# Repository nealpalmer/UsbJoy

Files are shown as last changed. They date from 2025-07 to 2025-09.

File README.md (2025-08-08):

# UsbJoy
USB Joystick Controller 12Digital/SmartButton, 4Analog, 1Rotary, 1NeoPixel

This is a couple of circuit boards that make up a fancy USB joystick controller for FRC #2984.
It has both a HID joystick interface and a HID uart interface (for configuration) presented to the computer (i.e. it works in Windows and Linux).  No embedded programming experience is necessary to get it to work!  It also looks like just a HID analog joystick to Windows.

To add to this readme+files:
- mechanical drawing of the board (wid, hei, hole locations)
- photo of driver's panel
- update code when I'm done fiddling with stuff
- Add pictures where appropriate (pickit programming, USB programming cable)
- A description of how to get feedback from the robot to the leds.  Does this require a networktables application?  Or use Force-Feedback mechanisms?






# Features:
- 12 Digital inputs for buttons (3-pin White/Yellow/Green JST XH: 5V, signal with 10k pullup, GND)
  - 12 is probably enough buttons for a FRC operator panel.  We use 2x of these on the operator panel, and 1 on the driver panel.
  - simple buttons and switches can be used, just connect to the 'signal' and 'GND' pins of the 3-pin connector, and ignore the '5V' pin.
- 4 Analog inputs for joysticks or linear/rotary potentiometers (10k ohms) (3-pin Blue JST XH: 5V, signal with 100k+100k pullup+pulldown, GND).
  - 1 Analog [joystick](https://www.amazon.com/dp/B08CGYGMJL) for driving (X & Y)
  - 2 [linear potentiometers](https://www.amazon.com/dp/B07HNY7VWC) are useful for controlling speeds or small adjustments to some positioning
  - There are more analog input pins that could be used for more analog inputs, but that is left upto the user to figure out if they care.  But it is probably simpler/cheaper just to make more of these boards.
- 1 Digital input can be used to drive a NeoPixel string (be careful of 500mA fuse) (3-pin Yellow)
  - Can mimic the robots LEDs (in case you can't see the robot)
  - Can give you feedback as to some positioning (i.e. target is to the left/right or up/down, and by how much)
  - Can give you feedback as to if you are holding the playing piece.
- 4-pin JST XH rotary encoder for Z-axis (600 ppr*4phase = 2400/rev resolution assumed)
  - We use the rotary encoder to control the angle that the robot is pointing on the field.  Turn the rotary knob by 5degrees, and the robot also turns by 5degrees...
- 4or5 extra 'virtual' buttons, 1 toggling (optional), 4 as constants
  - 4 virtual constant buttons make it possible to distinguish between multiple controllers easily.
  - Multiple UsbJoy boards can be distinguished from each other from the FRC Robot software (just use those constant buttons).  This means we don't have to re-arrange the joystick order in driver station.
- Arduino Pro Micro USB-C 5V ATmega32U4 controller board used for ease of soldering.
  - Make sure to get one with the fuse on the TOP side of the board (i.e. no bottom side components).  [amazon.com](https://www.amazon.com/gp/product/B0B6HYLC44)
- SmartButton support for all 12 Digital inputs
  - You can choose what each button's LED looks like for informational purposes.
  - Flickering the button when initially pressed is simple feedback that the button should be working (commuincation to UsbJoy, LED works, button works, cable connected appropriately).
  - Having the button light up when it should be useable is useful (i.e. the playing piece is being held, you can now press the shoot button).
  - Have a couple of buttons light up to indicate the state of the robot.
- 4 Digital connectors (Green) can have their 5V power switched on/off for use with simple led outputs (SmartButton requires it to always be powered on).
  - This sounded like a great idea initially, but I don't see a use for it now...
- ESD diodes on all 16 3-pin connectors
- Configuration of SmartButton settings done through the USB-UART interface.
  - Some settings are saved in EEPROM (Neopixel length, LED starting value, joystick invert axis, ...) , some are temporary (LED current values, neopixel pattern).
  - The settings are stored in the UsbJoy's EEPROM, and are configured for that particular port.  The settings aren't saved in the SmartButton itself.
  - You could compile different firmware for each button, and fix each button's LED functionality that way.
- Programming of PIC micro-controller done over USB-UART with MCLRn button press required (don't have anything plugged into J8, J11, J12).
- Programming of SmartButton PIC micro-controller over USB-UART (use a custom cable from J8+J11+J12 to SmartButton 5-pin header).
- Colored JST-XH 3-pin connectors are available on [aliexpress.com](https://www.aliexpress.us/item/3256806937445015.html)
- Colored JST-XH terminal 3-pin connectors are available on [aliexpress.com](https://www.aliexpress.us/item/3256804014172692.html)
- pre-crimped 3-pin cables are available on [aliexpress.com](https://www.aliexpress.us/item/3256807213104605.html)  Just be aware that the pins have to be removed, and swapped so that it is a 1:1 cable instead of a 1:3 cable (or you are going to connect GND to 5V, and destroy your SmartButtons).
- pre-crimped 10-pin cables are available on [amazon.com](https://www.amazon.com/dp/B0B2RCW5JF) And you would have to replace the connectors with a 3-pin version (cheap, and comes from US, so comes quickly).

# UsbJoy Connector description
- 
- J1-J12 are the button inputs.  Pin 1: 5V (square pad), Pin 2: 'signal' (short to GND during button press), Pin 3: GND.
- J7-J10 (Green connectors) can have their 5V pin switched on/off if you want to use an LED directly connected instead of a SmartButton.  They have a 100ohm series resistor for the 5V output to limit it to about 25mA (plenty for a SmartButton).
- J12 can be setup to drive a neopixel string (a programmable strip of RGB leds).  Be aware that the max current for the string should be about 400mA, any higher and the 500mA USB fuse on the Pro Micro is likely to blow.  So for very long strings, external power should be provided for the array.
- J13-J16 are the analog inputs.  Pin 1: 5V, Pin 2: analog signal, Pin 3: GND.
- J17 is the encoder input.  Pin 1: 5V (square pad), Pin 2,3: A&B encoder inputs, Pin 4: GND.  Any AB encoder can be used.  The firmware is setup to make a reasonable output for a 600 pulse/revolution=2400 change/revolution encoder (i.e. Z-axis has a range of 0-2399).  You can change the 2400 limit to any other number in the code for both the Arduino and PIC to make a different resolution encoder look right.
- J8, J11, J12 are used for PIC programming (both the UsbJoy and SmartButton PIC).
- Button between J17 and J5 is the PIC MCLRn button that connects J8.signal to MCLRn so that it is possible to program the PIC.
- J18 (5-pin holes on back side) is the PIC ICSP header.  Connect the PICKIT5 here.  You must disconnect PICKIT5 for normal operation.

# Rotary Encoder
- Uses a simple 4-pin {5V,A,B,GND} [encoder](https://www.amazon.com/dp/B01MZ4V1XP)
- 600pulses/revolution * 4 edges per pulse = 2400 positions/revolution (about 1/6degree resolution)
- Returns 0-2399 as the Z-axis to the Joystick HID interface.

# SmartButton features
- About $1 for circuit board+cpu+connector.  About $2 per illuminated arcade button.
- Designed to solder directly to 30mm illuminated arcade buttons. [amazon EG-Starts Illuminated 30mm](https://www.amazon.com/EG-STARTS-Illuminated-Buttons-Raspberry/dp/B01N11BDX9) [Aliexpress 30mm](https://www.aliexpress.us/item/3256804217382377.html) [Coin/1P/2P](https://www.aliexpress.us/item/2251832825468632.html) [AutoRGB](https://www.aliexpress.us/item/3256805580977933.html) [50pack 28mm](https://www.aliexpress.us/item/3256805775007172.html) [Free ship $10](https://www.aliexpress.us/item/2251832849688596.html)
- NOTE: 24mm illuminated buttons don't work, the pins are too close together and the button binds when the board is connected (unless you pre-bend the pins).  And they are only 1mm smaller diameter for the nut, so no reason to use them.
- Other buttons could be used.  Just solder the switch pins to the button, and the LED pins to an LED+Resistor.
- 3-pin interface (5V, signal, GND)
- Some solder jumpers can be filled, and some jumpers cut to turn a smart button into a dumb button (i.e. no 5V present).
- State of the led_option is stored in UsbJoy, and associated with the port.  So the buttons don't have to store their operational state.
- Programming of pic16f15213 can be done with either PicKit5 or UsbJoy.
- LED options
  - 0: OFF
  - 1: ON
  - 2: ON for 100ms when button gets pressed
  - 3: ON while button is pressed
  - 4: FLASHING 100ms on/100ms off
  - 5: SIN()
  - 6: FLASHING while button is pressed
  - 7: Button toggles state each time it is pressed: LED lit when in 'pressed' state
  - 8: Button toggles state each time it is pressed: LED flashes when in 'pressed' state
  - 9: you can add more if you want...

# NeoPixel
- Uses an off-the-shelf neopixel array (WS2812B 5V leds) [Strip_of_leds](https://www.amazon.com/dp/B09PBHJG6G) [ring_of_leds](https://www.amazon.com/dp/B08GPWVD57)
- Takes over Digital input #11 (the Yellow connector)
- You are going to have to make a cable that has the JST XH connector on the end of it.
- You MUST pay attention to the current draw of the string.  The entire UsbJoy is limited to 500mA, and if you draw much more than that, the fuse will blow, and everything will stop working.  So make sure that the length of string can't draw too much power.
- Possibly add an external power connection to power the neopixel array.
- Color choices:
  - 0x00-0x3f: Black-to-White solid color choices (4 values per R,G,B)
  - 0x80-0xff: Single white LED on (can be set to match the rotary encoder)
  - Rainbow
  - Moving Rainbow

# Files included:
- UsbJoy_d12_a4_r-rev2/: Kicad layout files, and gerbers
- SmartButton-rev2/: Kicad layout files, and gerbers
- UsbJoy_bill_of_materials.csv: spreadsheets with all of the parts to purchase and quantities and ordering links, pcb, buttons, cables, other stuff...
- mechanics/: openscad & STL files for a couple of mounts for UsbJoy using the SmartButton, rotary dial, 
- software/SmartButton_firmware/:
- software/UsbJoy_firmware/: firmware for the Atmega32U4 microcontroller
- software/UsbJoy_pic_firmware/: firmware 
- software/program_pic/: small application to program the pic16f1778 on UsbJoy, and pic15f15213 on SmartButton

# Manufacturing suggestions:
- [oshpark.com](https://oshpark.com/) has wonderful pricing for qty3 of 2and4 layer boards and ships in 10 calendar days for almost everything (and you can pay more to get it earlier, or pay for faster shipping)
  - [UsbJoy_R2](https://oshpark.com/shared_projects/QPZCB1ZT) board order $20/3 boards
  - [SmartButton_R2](https://oshpark.com/shared_projects/OV1uAkH7) board order $1.70/3 boards ($6.80/12 boards)
- A 3d-printer can make the UsbJoy board attach directly to the screw threads of one of the buttons.  A couple of sample mount's source files are [here](https://makerworld.com/en/models/1602536-usbjoy-controller-mount-30mm-arcade-button).
- An 3d printed [encoder spring](https://makerworld.com/en/models/1602721-rotary-encoder-rotary-friction-spring) makes the encoder much better for not spinning the robot wildly.
- An [acrylic wheel](https://makerworld.com/en/models/1605249-encoder-finger-wheel) with finger holes for the encoder is very useful.
- Testing for button functionality can be done in windows with the built-in "USB game controllers"->properties window to see the buttons that get pressed. NEED A PICTURE HERE!
- You can extract a 3d model of the boards from kicad to use in your 3d cad system.  Kicad: File->Export->STEP
- digikey has all of the electrical components necessary (except for the LED and Arduino board).
- 3x UsbJoy parts kit
- 12x SmartButton parts kit
- The arduino pro micro has a 0.5A fuse on it.  The bottom side of the board will NOT be accessible.  If that 0.5A fuse is on the bottom side, and you have over current, then your boards will not be salvageable.  So get a version that has all the components on the top side.
- The discrete components are 0603 packages for easier soldering.
- Get some [illuminated magnifying glasses](https://www.amazon.com/YOCTOSUN-Magnifying-Rechargeable-1-5X-3-5X-Magnifier/dp/B0D8J3TYL3) for ease of soldering of small components. 
- Solder all of the SMT components before any thru-hole components.  Required for both boards, because some of the thru-hole soldering will make SMT parts unreachable.

# How to program Arduino Pro Micro's Atmega32U4 (the USB device):
- Run the [Arduino GUI](https://www.arduino.cc/en/software/) version 1.8.19 (or newer than May 2025).
- Load the *.ino file
- Set up the board to be "Arduino Leonardo".
- Plug in the board into USB, then select the right Com port in the Arduino GUI.
- "Upload" 
 from the Arduino GUI.
- Programming does not clear the EEPROM, so any settings should remain unaffected.

# How to program pic16f1778 on UsbJoy using PICKIT5 programmer:
- Disconnect the last 2 buttons (Yellow and white next to each other)
- type "q1" on the uart to disable the 7,10,11 button communications
- Run the [Microchip IDE](https://www.microchip.com/en-us/tools-resources/develop/mplab-x-ide)
- Load the project
- Compile the project for production
- Use one of the current PIC programmers (pickit5 is probably preferred), and plug it into the 5-pin holes on the bottom side of the board.  And have the IDE program the device.
- type "q0" on the uart to re-enable the last 2 button functionality
# How to program pic16f1778 on UsbJoy using UsbJoy's USB connection:
- Disconnect buttons 7,10,11 (Green, White, Yellow) - they will interfere with the programming.
- Connect UsbJoy to the Windows PC.
- Figure out what com port (use Windows Device Manager) UsbJoy is using.
- Run "program_pic.exe usbjoy [filename].hex COM[#]"
- Press and hold the button next to the rotary connector for the full programming time (about 15 seconds).  If you forget this step, then you will receive a message "Error: couldn't find expected PIC CPU".
- Wait for programming to complete.
- Release the button.
- You can now reconnect the disconnected buttons.

# How to program pic16f15213 on SmartButton using PICKIT5:
- Run the [Microchip IDE](https://www.microchip.com/en-us/tools-resources/develop/mplab-x-ide)
- Load the project
- Compile the project for production
- Make sure the SmartButton isn't pressed, Connect the 3-pin cable to the UsbJoy (for 5V power), plug the pickit5 into the 5-pin holes on the SmartButton board.  And have the IDE program the device.
# How to program pic16f15213 on SmartButton using UsbJoy's USB interface:
- Connect 3+3+3pin cable ends into UsbJoy (match yellow J12,white J11,green J8 connectors), connect 5-pin cable end into SmartButton.
- Run "program_pic sb smartbutton.hex COM[#]".
- Quick Test: While plugged into the 5-pin cable, you should see the led in the button flicker VERY VERY dim.
- Quick Test: While plugged into the 5-pin cable, if you press the button, the LED should light up.
- You will need to create a cable to connect J8,J11,J12 to a 5-pin header.  It is probably easiest and more reliable to make an 3+3+3-pin to 5-pin XH only cable, and then solder the B5B-XH header to a 0.1" header.
 - pin1: MCLRn -> Red/Green/J8.2
 - pin2: 5V -> White/White/J11.1
 - pin3: GND -> Blue/Yellow/J12.3
 - pin4: PGD -> Blue/Yellow/J12.2
 - pin5: PGC -> White/White/J11.2
 - 
 - 

# How to initially configure UsbJoy:
- Connect USB to a PC.
- Open a terminal program (I like [MobaXterm](https://mobaxterm.mobatek.net/)), and connect to the correct com port (use windows device manager, and find the 'leonardo' port listed) (linux: 'dmesg' to find the correct '/dev/ttyUSB#' when you plug into USB).
- Any baud rate is fine, because it is a virtual serial port.
- 'h'+enter to get the help menu
- All settings commands are "letter+hex_number+enter".
- Important EEPROM settings to run:
  - 'u#" to set the upper 4 bits for the virtual buttons to uniquely identify this particular board (saved to EEPROM)
  - "m#val" to set the SmartLed DEFAULT setting for that port (not for the SmartLed itself) to the desired LED pattern (and toggle functionality) (saved to EEPROM)
  - "n#" to set the number of neopixel leds in the string - set to "n0" to indicate that there isn't a neopixel string.
  - "v#" to set the power-on setting for the Green ports - probably want them always on "vF" unless they are being used in some interesting way.
  - "V#" to set the power-on DEFAULT for the Green ports (saved to EEPROM)

# Future enhancements
- Add a 5-pin direct programming header for connecting to SmartButton (no need for weird programming cable).
- Move QR code to top side of board.

# History of major changes
- 8/8/2025: Added RZ axis to have the full resolution of the 2400/rev encoder when used with FRC DriverStation that only has 200 values per axis.
- 7/16/2025: Added MPLAB project files.
- 7/16/2025: SmartButton pic programming working over USB
- 7/16/2025: Added PDF of schematics.
- 7/15/2025: Uploaded 3d and lasercut objects to makerworld.com

Neal Palmer,
**FRC team #2984 Vikings Robotics,**
La Jolla, CA, USA

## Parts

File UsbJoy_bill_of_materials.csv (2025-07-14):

Description | ref des | $/each | total Qty | Qty/UsbJoy | Qty/SmartButton | Qty other | Purchasing link
Oshpark UsbJoy 3x UsbJoy PCB |  | $7.00 | 1 | 1 |  |  | https://oshpark.com/shared_projects/QPZCB1ZT
Digikey kit of 3x UsbJoy parts |  |  | 1 | 1
Oshpark SmartButton 3x SmartButton PCB |  | $0.50 | 1 |  | 1 |  | https://oshpark.com/shared_projects/OV1uAkH7
Digikey kit of 12x SmartButton parts |  |  | 1 |  | 1
30mm illuminated arcade buttons (5x) |  | $2.00 | 1 |  | 1 |  | https://www.amazon.com/dp/B01N11BDX9
600ppm encoder |  | $16.99 | 1 |  |  | 1 | https://www.amazon.com/dp/B01MZ4V1XP
encoder finger wheel |  | laser cut | 1 |  |  | 1 | https://makerworld.com/en/models/1605249-encoder-finger-wheel
UsbJoy mount to SmartButton |  | printed plastic | 1 |  |  | 1 | https://makerworld.com/en/models/1602536-usbjoy-controller-mount-30mm-arcade-button
encoder springs |  | printed plastic | 1 |  |  | 1 | https://makerworld.com/en/models/1602721-rotary-encoder-rotary-friction-spring
analog joystick |  | $17.89 | 1 |  |  | 1 | https://www.amazon.com/dp/B08CGYGMJL
linear potentiometer |  | $2.00 | 2 |  |  | 2 | https://www.amazon.com/dp/B07HNY7VWC
JST XH 3-pin connector end |  |  | 32 |  |  | 32
JST XH crimp pins |  |  | 96 |  |  | 96
XH wires with 5-pin connectors (need to replace with 3-pin) (20 pieces) |  | $0.44 | 1 |  |  | 1 | https://www.amazon.com/dp/B0B2RCW5JF
magnifying glasses |  | $23.99 | 0 |  |  |  | https://www.amazon.com/Dilzekui-Magnifier-Rechargeable-Magnifying-Optivisor/dp/B0C7LNGKLP
neopixel string |  | $14.99 | 1 |  |  | 1 | https://www.amazon.com/dp/B09PBHJG6G
neopixel ring |  | $25.99 | 1 |  |  | 1 | https://www.amazon.com/dp/B083VWVP3J?ref_=ppx_hzsearch_conn_dt_b_fed_asin_title_2&th=1
B3B-XH-A (white JST XH 3-pin) | J1, J2, J3, J4, J5, J6, J11 |  | 7 | 7
B3B-XH-A (green JST XH 3-pin) | J7, J8, J9, J10 |  | 4 | 4
B3B-XH-A (blue JST XH 3-pin) | J13, J14, J15, J16 |  | 4 | 4
B3B-XH-A (yellow JST XH 3-pin) | J12 |  | 1 | 1
B4B-XH-A (white JST XH 4-pin) | J17 |  | 1 | 1
Pro Micro Arduino with USB-C | U1 |  | 1 | 1
CD74HC243M96 (SOIC 14, 5V, buffer) | U3 |  | 1 | 1
pic16f1778 (SOIC 28, 5V) | U2 |  | 1 | 1
Green LED 0603 | D1 |  | 1 | 1
100k 0603 5% resistor | R25, R26, R27, R28, R21, R22, R23, R24 |  | 8 | 8
10k 0603 5% resistor | R7, R1, R2, R19, R18, R17, R16, R15, R14, R13, R12, R9, R10, R11, R20 |  | 15 | 15
2k 0603 5% resistor | R8 |  | 1 | 1
DRTR5V0U2SR-7 (esd diode) | CR1, CR2, CR3, CR4, CR5, CR6, CR7, CR8 |  | 8 | 8
10uF 6.3V 1210 ceramic capacitor | C3, C4 |  | 2 | 2
0.1uF 6.3V 0603 ceramic capacitor | C1, C2 |  | 2 | 2
450-1140-ND (momentary push button) | SW1 |  | 1 | 1
100ohm 0603 5% resistor | R3, R4, R5, R6 |  | 4 | 4
 |  |  | 0
 |  |  | 0
B3B-XH-A (white JST XH 3-pin) | J2 |  | 1 |  | 1
0.01uF 0603 6.3V ceramic capacitor | C1 |  | 1 |  | 1
10k 0603 5% resistor | R1, R2 |  | 2 |  | 2
pic16f15213-I/SN (soic8, 5V) | U1 |  | 1 |  | 1
DRTR5V0U2SR-7 (esd diode) | CR1 |  | 1 |  | 1
 |  |  | 0
 |  |  | 0
 |  |  | 0
 |  |  | 0
 |  |  | 0
 |  |  | 0
 |  |  | 0
 |  |  | 0
 |  |  | 0
 |  |  | 0
 |  |  | 0
 |  |  | 0
 |  |  | 0
 |  |  | 0

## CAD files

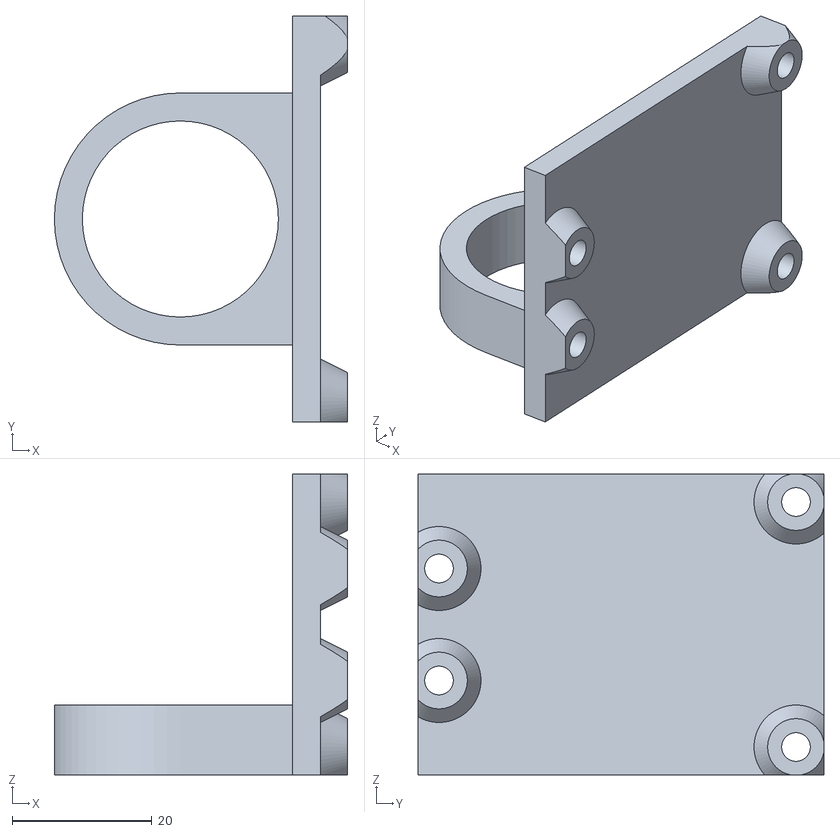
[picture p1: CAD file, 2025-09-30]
mechanics/usb_joystick_mount_vertical.stl
41.9 x 58.0 x 43.0

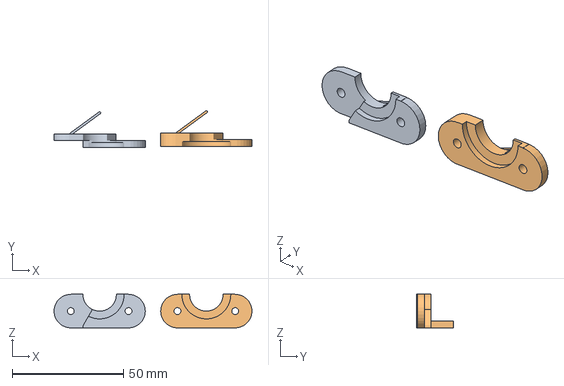
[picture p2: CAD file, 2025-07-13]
mechanics/rotary_friction.3mf
89.1 x 16.5 x 15.1 mm
rotary_friction.stl_2
rotary_friction.stl_3

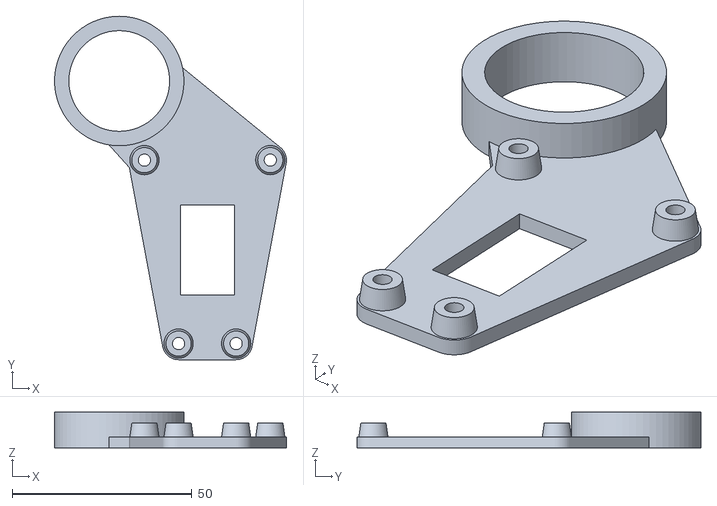
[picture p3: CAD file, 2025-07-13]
mechanics/usb_joystick_mount_horizontal.stl
64.5 x 95.5 x 10.0

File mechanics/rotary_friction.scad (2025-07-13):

INCH = 25.4;

module encoder() {
	difference() {
		union() {
				// base of encoder
			translate([0,0,-1-0.115*INCH])
				cylinder(d=38,h=1,$fn=100);

				// rim of encoder
			translate([0,0,-0.115*INCH])
				cylinder(d=20,h=5,$fn=100);

				// shaft of encoder
			translate([0,0,-0.115*INCH+5])
				cylinder(d=6,h=13,$fn=100);

				// flange
			translate([0,0,-0.115*INCH+5+13-2])
				cylinder(d=22,h=2,$fn=100);
		}

			// M3 holes
		for (a=[0,120,240]) {
			rotate(a=a,v=[0,0,1])
				translate([0,28/2,-10])
					cylinder(d=3,h=20,$fn=30);
			rotate(a=a-30,v=[0,0,1])
				translate([0,30/2,-10])
					cylinder(d=3,h=20,$fn=30);
		}
	}
}

M3_D = 3.1;
HOLE_DIST = 30*cos(30);
WALL=6;
BASE = 6;
SPRING_THICK = 1;
SPRING_HEI = 3;

module springy(index) {
	difference() {
		union() {
				// base
			hull () {
				translate([(index==0) ? HOLE_DIST/3+5 : 0,0,0])
					cube([(index==0) ? HOLE_DIST*2/3-5 : HOLE_DIST,BASE/2,M3_D+2*WALL]);
				translate([(M3_D+2*WALL)/2-2,0*BASE/2,0])
					cube([HOLE_DIST*2/3,BASE/2,(M3_D+2*WALL)/2*0+1]);
			}
			hull () {
				translate([0,BASE/2,0])
					cube([HOLE_DIST*2/3-5,BASE/2,M3_D+2*WALL]);
				translate([HOLE_DIST/3+3,BASE/2,0])
					cube([HOLE_DIST*2/3-(M3_D+2*WALL)/2-1,BASE/2,(M3_D+2*WALL)/2*0+1]);
			}

				// 2 mounting holes
			translate([0,(index==0) ? BASE/2 : 0,1.5+WALL])
				rotate(a=-90,v=[1,0,0])
					cylinder(d=M3_D+2*WALL,h=BASE/((index==0) ? 2 : 1),$fn=30);
			translate([HOLE_DIST,0,1.5+WALL])
				rotate(a=-90,v=[1,0,0])
					cylinder(d=M3_D+2*WALL,h=BASE/2,$fn=30);
		}
			// 2 mounting holes
		for (x=[0,HOLE_DIST])
			translate([x,0,1.5+WALL])
				rotate(a=90,v=[1,0,0])
					cylinder(d=3.1,h=100,center=true,$fn=30);

			// center flange cut
		translate([HOLE_DIST/2,-1,HOLE_DIST*sin(30)/cos(30)])
			rotate(a=90,v=[-1,0,0])
				cylinder(d=22,h=5-0.115*INCH+1,$fn=100);
		translate([HOLE_DIST/2,-1,HOLE_DIST*sin(30)/cos(30)])
			rotate(a=90,v=[-1,0,0])
				cylinder(d=15,h=50-0.115*INCH+1,$fn=100);
	}
	// 2 springs?
	hull() {
		translate([0,BASE,0])
			cylinder(d=SPRING_THICK,h=SPRING_HEI,$fn=20);
		translate([HOLE_DIST/2,15.5,0])
			cylinder(d=SPRING_THICK,h=SPRING_HEI,$fn=20);
	}
}


color("grey")
encoder();


translate([50,0,0])
springy(0);

translate([100,0,0])
springy(120);


for (a=[0,120])
rotate(a=a,v=[0,0,1])
translate([0,15,0])
	rotate(a=90,v=[1,0,0])
		rotate(a=60,v=[0,-1,0])
			translate([0,0,-WALL-M3_D/2])
				springy(a);

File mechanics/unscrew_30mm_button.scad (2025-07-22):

id = 23;
od = 26;
wall = 2;
tab_wid = 15;
tab_hei = 6;

bottom_h = 1.5;

hei = 20;

module unscrew_30mm_button() 
{
	// outer strong pipe
 if (1)
 difference() {
 	cylinder(d=od+wall*2, h=hei, $fn=100);
	translate([0,0,-0.1])
 		cylinder(d=od, h=hei+1, $fn=100);
 }

	// 
 difference() {
	translate([0,0,bottom_h])
		cylinder(d=od, h=hei-bottom_h, $fn=100);

		// remove an overhang
	//translate([0,0,bottom_h-0.001])
 		//cylinder(d1=od, d2=1, h=od/2, $fn=100);
	translate([0,0,-0.1])
 		cylinder(d=id, h=hei*2, $fn=100);
	
	hull() {
		intersection() {
			//cylinder(d=od,h=tab_hei+bottom_h,$fn=100);
			translate([-50,-tab_wid/2,0])
				cube([100,tab_wid,tab_hei+bottom_h]);
		}
			// remove an overhang
		//cylinder(d=1,h=tab_hei+bottom_h+od/4);
	}
 }

 for (a=[0,180]) rotate(a=a,v=[0,0,1]) {
	difference() {
		union() {
 			translate([od/2,-10,hei-10])
				cube([12,10,10]);
 			translate([od/2-3,-10,hei-10])
				cube([4,4,10]);
		}
 		translate([od/2+wall+15/2,0,hei-10.1])
 			cylinder(d=15,h=10.2,$fn=30);
	}
 }
}
unscrew_30mm_button();

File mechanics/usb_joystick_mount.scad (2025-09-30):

	// usbjoystick board dimensions and hole locations
usbjoy_w = 43;
usbjoy_l = 58;
usbjoy_thick = 1.6; // 0.062" PCB thickness
x1 = 104.5; y1 = 113;
x2 = 120.5; y2 = 113;
x3 = 95; y3 = 62;
x4 = 130; y4 = 62;
l = 91; r = 134; lr = (l+r)/2;
b = 58; t = 116; bt = (b+t)/2;
//usbjoy_holes = [[-17, 23], [17,23], [-10,-23], [10,-23]];
usbjoy_holes = [[x1-lr, bt-y1], [x2-lr,bt-y2], [x3-lr,bt-y3], [x4-lr,bt-y4]];
usbjoy_x = 3;

BASE = 4;

button_d = 28;
button_nut_d = 36;

m3_d = 3.2; // really is 3.0mm
m3_wall = 2;
m3head_d = 6; // really is 5.5mm
m3head_len = 3.5; // really is 3mm
m3_len = 10;
m3locknut_hei = 4;

//usbjoy_standoff_height = 4;
usbjoy_standoff_height = m3_len+m3head_len - BASE - usbjoy_thick - m3locknut_hei;

USBC_W = 12.5;

wall = 4; // happens to be the added radius of the button_nut

module mount_flat() {
	difference() {
		union() {
				// ring around button
			cylinder(d=button_d+2*wall, h=10, $fn=60);

				// base for board
			hull () {
				cylinder(d=button_d, h=3, $fn=60);
				//translate([usbjoy_x,-usbjoy_l/10-button_d/2-wall,0]) {
					//cube([usbjoy_w,usbjoy_l/10,3]);
					//translate([usbjoy_w/2-12.5/2,usbjoy_l,5])
						//color("red") cube([12.5,36,7.5]); // usb-c cable end
				//}
				for (xy=[usbjoy_holes[2],usbjoy_holes[3]]) {
					translate([usbjoy_x+xy[0]+usbjoy_w/2,-usbjoy_l/2-button_nut_d/2+xy[1],0])
						cylinder(d=9,h=3,$fn=60);
				}
			}
			hull () {
				for (xy=usbjoy_holes) {
					translate([usbjoy_x+xy[0]+usbjoy_w/2,-usbjoy_l/2-button_nut_d/2+xy[1],0])
						cylinder(d=9,h=3,$fn=60);
				}
			}
			//translate([usbjoy_x,-usbjoy_l-button_d/2-wall,0])
				//cube([usbjoy_w,usbjoy_l,3]);

				// standoffs for board
			for (xy=usbjoy_holes) {
				translate([usbjoy_x+xy[0]+usbjoy_w/2,-usbjoy_l/2-button_nut_d/2+xy[1],0])
					cylinder(d1=9,d2=3+4,h=3+usbjoy_standoff_height,$fn=60);
			}
		}

			// hole for button
		cylinder(d=button_d, h=3*10, $fn=60, center=true);

			// holes for bolts
		for (xy=usbjoy_holes) {
			translate([3+xy[0]+usbjoy_w/2,-usbjoy_l/2-button_nut_d/2+xy[1],-0.1]) {
				cylinder(d=3.4,h=30,$fn=60);
				cylinder(d=m3head_d,h=m3head_len+0.1,$fn=60);
				translate([0,0,m3head_len+0.09])
					cylinder(d1=m3head_d,d2=3.0,h=0.75,$fn=60); // chamfer so that support isn't needed
			}
		}

			// hole for PIC programming header
		translate([3+usbjoy_w/2-15/2,-usbjoy_l/2-button_nut_d/2-25/2,-1])
			cube([15,25,10]);
	
	}
}

module mount_vert(drill_dia) {
	difference() {
		union() {
				// ring around button
			cylinder(d=button_d+2*wall, h=10, $fn=60);

				// nut diameter
			//translate([0,0,12])
			//#cylinder(d=button_nut_d,h=2,$fn=60);

				// base for board
			hull () {
				cylinder(d=button_d+2*wall, h=10, $fn=60);
				translate([button_nut_d/2-wall/2,-button_nut_d/2,0])
					cube([wall,button_nut_d,10]);
			}
			translate([button_nut_d/2-wall/2,-usbjoy_l/2,0]) {
				cube([wall,usbjoy_l,usbjoy_w]);
			}

				// standoffs for board
			intersection() {
				translate([button_nut_d/2-wall/2,-usbjoy_l/2,0]) {
					cube([wall+usbjoy_standoff_height,usbjoy_l,usbjoy_w]);
				}
				for (xy=usbjoy_holes) {
					translate([button_nut_d/2+wall/2-0.01,xy[1],usbjoy_w/2+xy[0]])
						rotate(a=90,v=[0,1,0])
							cylinder(d1=drill_dia+2*m3_wall+usbjoy_standoff_height,d2=drill_dia+2*m3_wall,h=0*wall+usbjoy_standoff_height,$fn=60);
				}
			}
		}

			// hole for button
		cylinder(d=button_d, h=3*10, $fn=60, center=true);
			// hole for button's nut
		translate([0,0,10+0.01])
			cylinder(d=button_nut_d+1, h=10, $fn=60);
		translate([0,0,20-0.01])
			cylinder(d1=button_nut_d+1, d2=button_nut_d-wall, h=20, $fn=60);

			// holes for bolts
		for (xy=usbjoy_holes) {
			translate([button_nut_d/2,xy[1],usbjoy_w/2+xy[0]])
				rotate(a=90,v=[0,1,0])
					cylinder(d=drill_dia,h=wall+1.5+10,$fn=60,center=true);
		}
	
	}
}

if (0)
translate([100,0,0])
mount_flat();

if (0)
mount_vert(3.3);
if (1)
mount_vert(4.1); // for heat set nuts

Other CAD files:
mechanics/rotary_friction.stl

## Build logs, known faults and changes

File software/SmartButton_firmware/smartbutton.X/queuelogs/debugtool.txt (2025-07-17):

1321 1751653072935 GEN4_TO_CONTROLLER_LOG:GEN4_DEBUG_INT_LOG_PIC16F15213 Pre:DebugReadTargetMemory
1321 1751653072935 GEN4_TO_CONTROLLER_LOG:GEN4_DEBUG_INT_LOG_PIC16F15213 Payload
1321 1751653072935 GEN4_TO_CONTROLLER_LOG:GEN4_DEBUG_INT_LOG_PIC16F15213 FileRegs
1321 1751653072935 GEN4_TO_CONTROLLER_LOG:GEN4_DEBUG_INT_LOG_PIC16F15213 3
1321 1751653072935 GEN4_TO_CONTROLLER_LOG:GEN4_DEBUG_INT_LOG_PIC16F15213 3
1321 1751653072935 GEN4_TO_CONTROLLER_LOG:GEN4_DEBUG_INT_LOG_PIC16F15213 Length = 1
1321 1751653072935 GEN4_TO_CONTROLLER_LOG:GEN4_DEBUG_INT_LOG_PIC16F15213 Payload End
1321 1751653072935 XXXX 1751653072935, Thread 1321: XXXX 1751653072935, Entering Thread 1321: Commands::runScriptWithUpload, script name = ReadRAM  
1321 1751653072935 XXXX 1751653072935, Thread 1321: XXXX 1751653072935, Entering Thread 1321: ToolCommUsb::readTransfer, sideData is 0x25 bytes long, transferDataLength is 0x1 bytes long  
1321 1751653072936 XXXX 1751653072936, Thread 1321: com.Send returned false 
1321 1751653072936 XXXX 1751653072936, Thread 1321: readTransfer: exception after writeHeaderAndGetAck null 
1321 1751653072936 XXXX 1751653072936, Thread 1321: XXXX 1751653072936, Entering Thread 1321: ToolCommUsb::recoverFromProtocolError, type = NO_SCRIPT  
1321 1751653072936 XXXX 1751653072936, Thread 1321: Send Abort Script Engine Command 
1321 1751653072936 XXXX 1751653072936, Thread 1321: XXXX 1751653072936, Entering Thread 1321: ToolCommUsb::killScriptEngine  
1321 1751653072936 XXXX 1751653072936, Thread 1321: com.Send returned false 
1321 1751653072936 XXXX 1751653072936, Thread 1321: Failed sending Abort Script Engine Command. Set nuclear option = true 
1321 1751653072936 XXXX 1751653072936, Thread 1321: About to nuke 
1321 1751653072936 XXXX 1751653072936, Thread 1321: XXXX 1751653072936, Entering Thread 1321: ToolCommUsb::nuclearOption  
1321 1751653072936 XXXX 1751653072936, Thread 1321: com.Send returned false

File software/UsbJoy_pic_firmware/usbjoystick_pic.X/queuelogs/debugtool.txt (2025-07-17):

21387 1751823510791 GEN4_TO_CONTROLLER_LOG:GEN4_DEBUG_INT_LOG_PIC16F1778 Pre:DebugReadTargetMemory
21387 1751823510791 GEN4_TO_CONTROLLER_LOG:GEN4_DEBUG_INT_LOG_PIC16F1778 Payload
21387 1751823510791 GEN4_TO_CONTROLLER_LOG:GEN4_DEBUG_INT_LOG_PIC16F1778 FileRegs
21387 1751823510791 GEN4_TO_CONTROLLER_LOG:GEN4_DEBUG_INT_LOG_PIC16F1778 3
21387 1751823510791 GEN4_TO_CONTROLLER_LOG:GEN4_DEBUG_INT_LOG_PIC16F1778 3
21387 1751823510791 GEN4_TO_CONTROLLER_LOG:GEN4_DEBUG_INT_LOG_PIC16F1778 Length = 1
21387 1751823510791 GEN4_TO_CONTROLLER_LOG:GEN4_DEBUG_INT_LOG_PIC16F1778 Payload End
21387 1751823510791 XXXX 1751823510791, Thread 21387: XXXX 1751823510791, Entering Thread 21387: Commands::runScriptWithUpload, script name = ReadRAM  
21387 1751823510791 XXXX 1751823510791, Thread 21387: XXXX 1751823510791, Entering Thread 21387: ToolCommUsb::readTransfer, sideData is 0x25 bytes long, transferDataLength is 0x1 bytes long  
21387 1751823510792 XXXX 1751823510792, Thread 21387: com.Send returned false 
21387 1751823510792 XXXX 1751823510792, Thread 21387: readTransfer: exception after writeHeaderAndGetAck null 
21387 1751823510792 XXXX 1751823510792, Thread 21387: XXXX 1751823510792, Entering Thread 21387: ToolCommUsb::recoverFromProtocolError, type = NO_SCRIPT  
21387 1751823510792 XXXX 1751823510792, Thread 21387: Send Abort Script Engine Command 
21387 1751823510792 XXXX 1751823510792, Thread 21387: XXXX 1751823510792, Entering Thread 21387: ToolCommUsb::killScriptEngine  
21387 1751823510792 XXXX 1751823510792, Thread 21387: com.Send returned false 
21387 1751823510792 XXXX 1751823510792, Thread 21387: Failed sending Abort Script Engine Command. Set nuclear option = true 
21387 1751823510792 XXXX 1751823510792, Thread 21387: About to nuke 
21387 1751823510792 XXXX 1751823510792, Thread 21387: XXXX 1751823510792, Entering Thread 21387: ToolCommUsb::nuclearOption  
21387 1751823510793 XXXX 1751823510793, Thread 21387: com.Send returned false

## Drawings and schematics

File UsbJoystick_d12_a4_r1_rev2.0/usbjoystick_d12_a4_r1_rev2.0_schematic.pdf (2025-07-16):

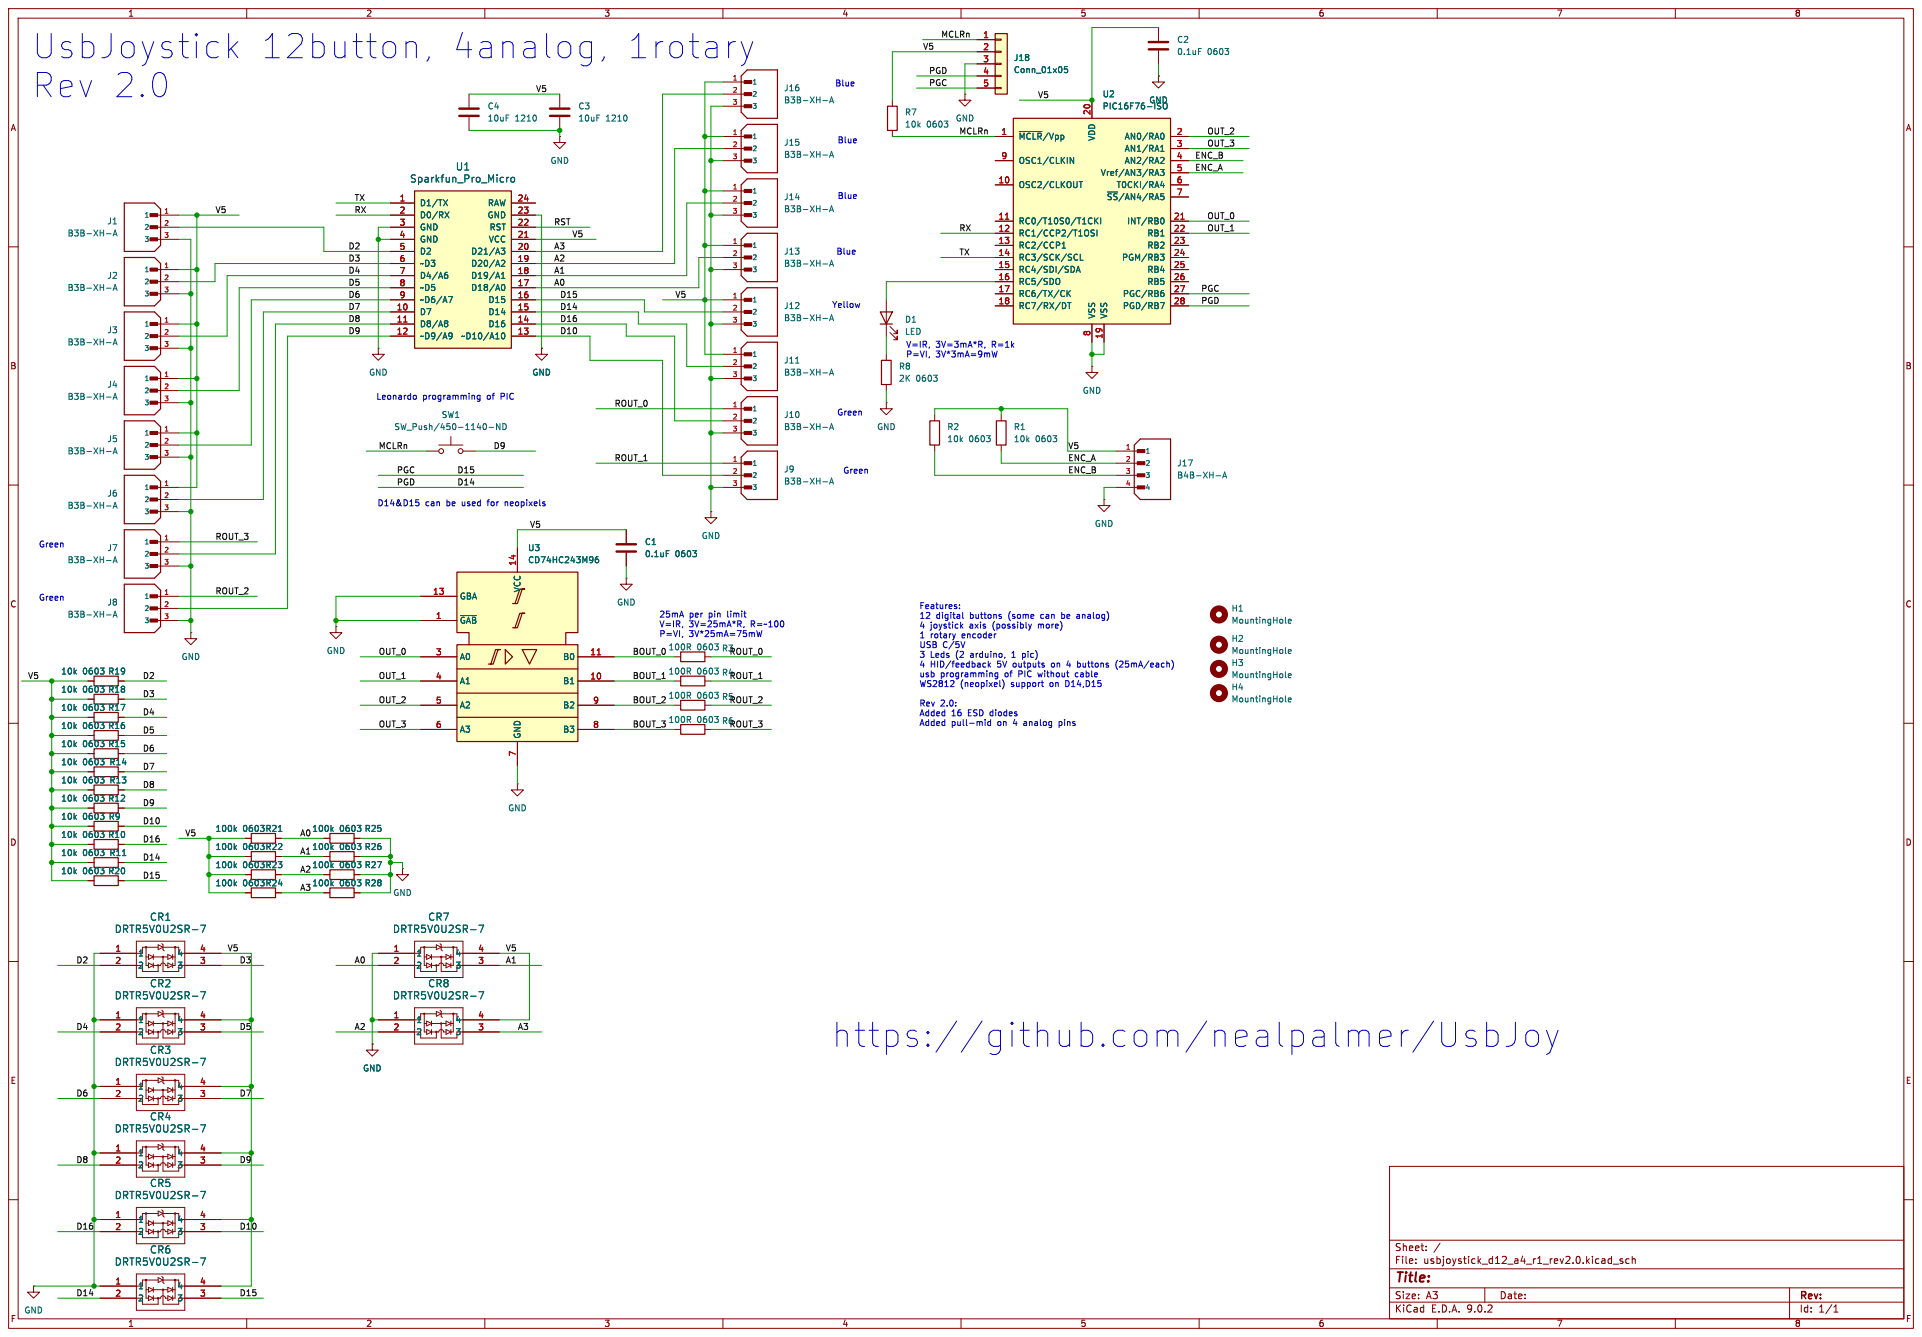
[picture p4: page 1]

D14&D15 can be used for neopixels Green Green

Id: 1/1 Title: File: usbjoystick_d12_a4_r1_rev2.0.kicad_sch Sheet: /

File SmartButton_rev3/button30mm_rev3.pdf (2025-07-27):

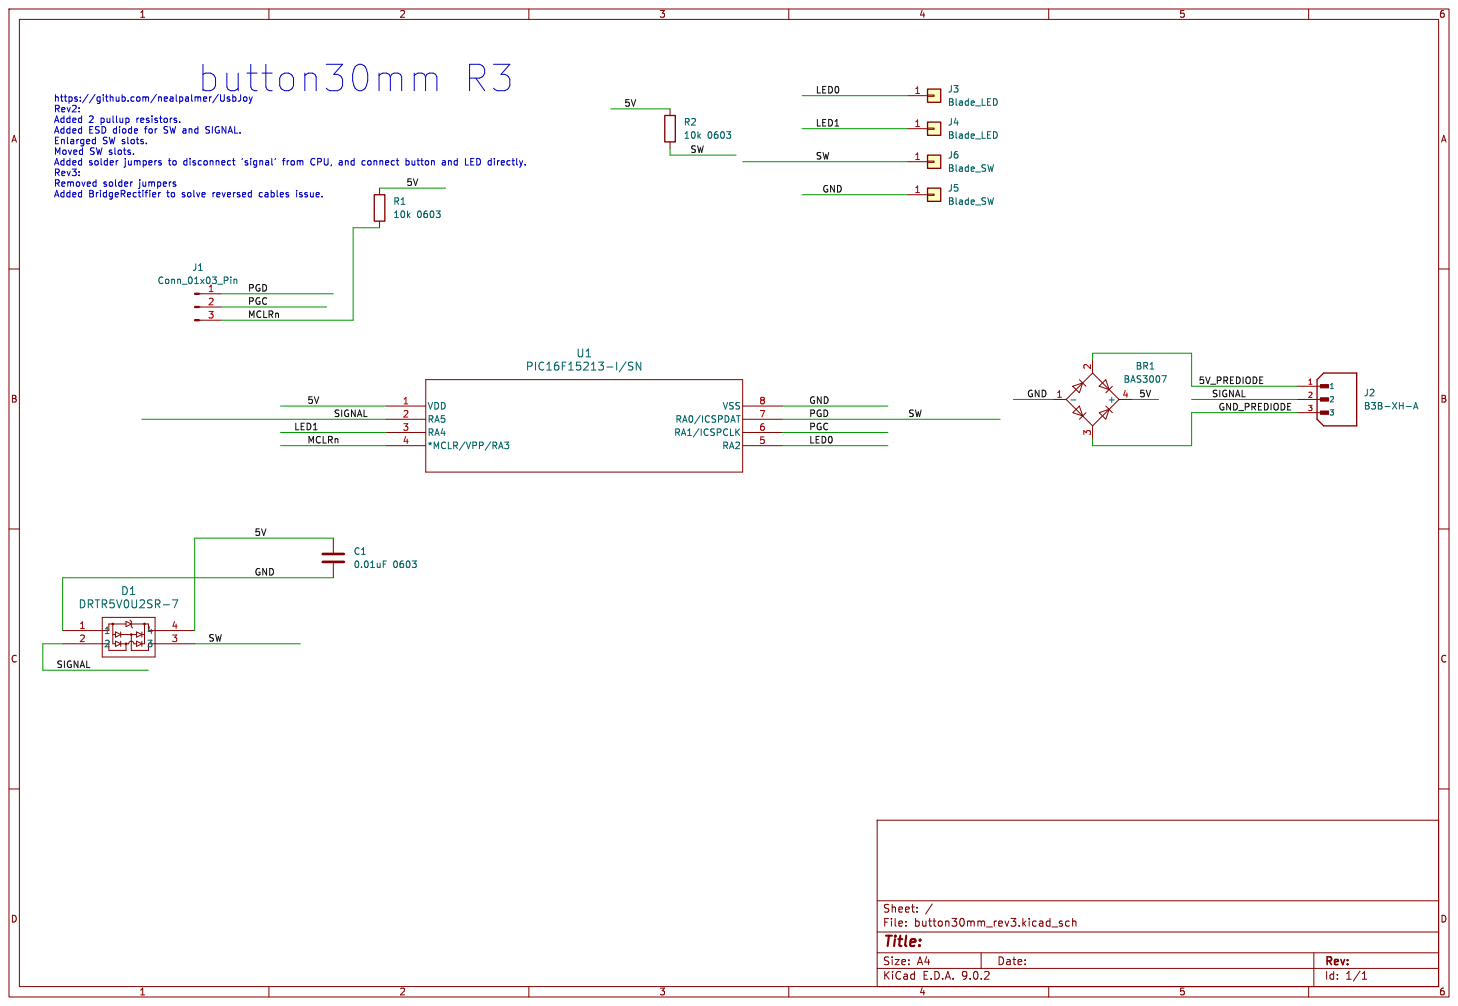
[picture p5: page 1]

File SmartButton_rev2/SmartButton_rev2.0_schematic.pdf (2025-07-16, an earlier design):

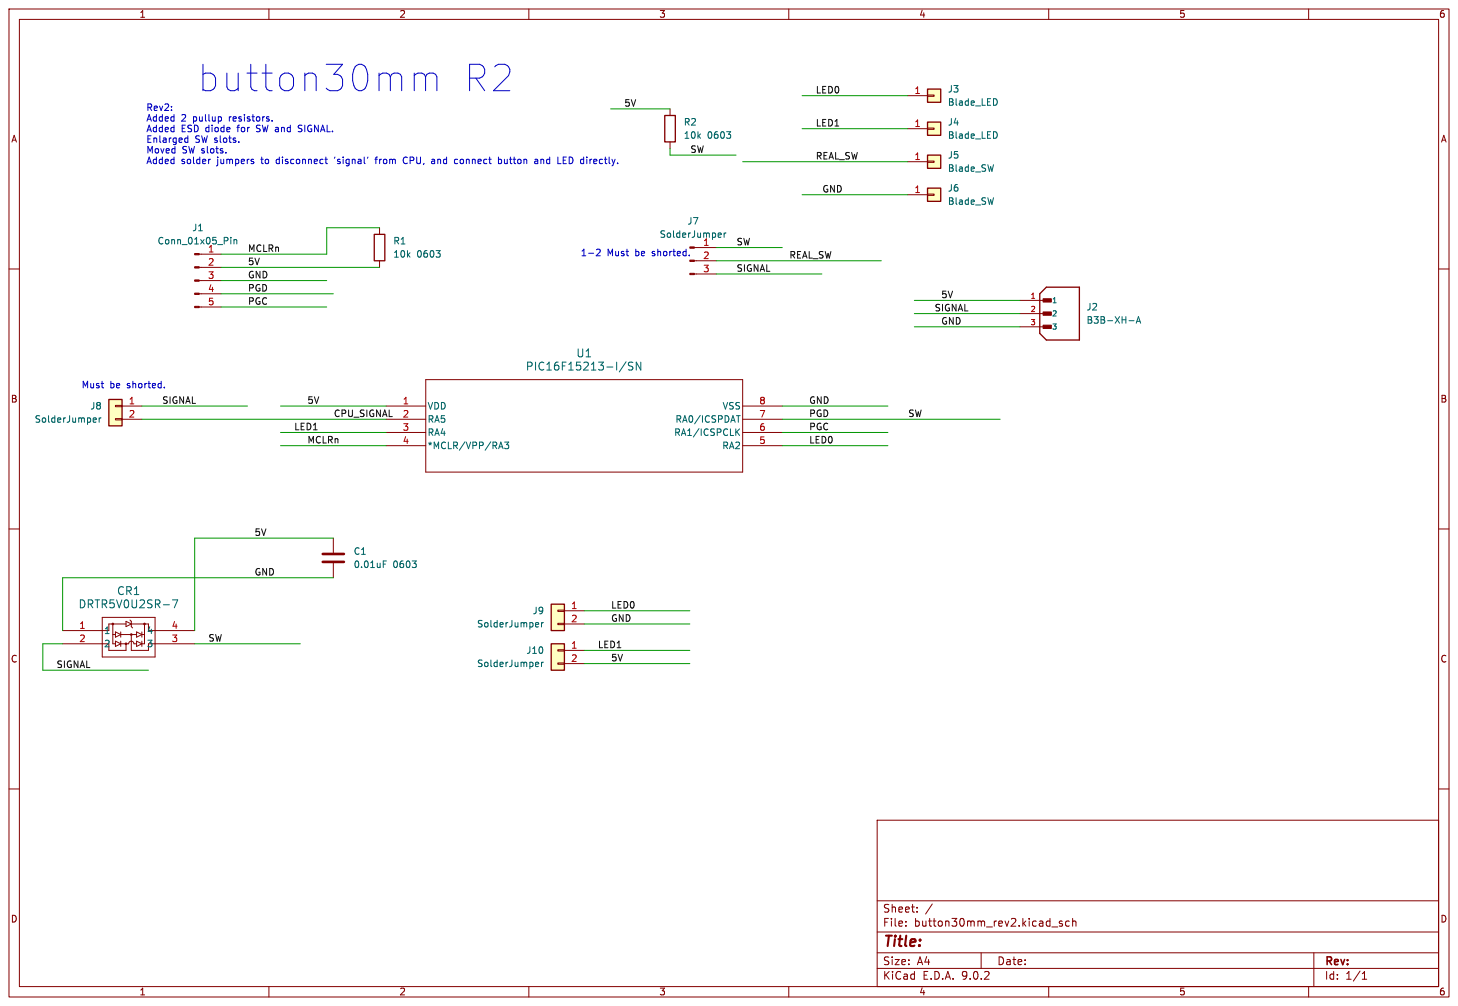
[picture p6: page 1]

Id: 1/1 Title: File: button30mm_rev2.kicad_sch Sheet: /

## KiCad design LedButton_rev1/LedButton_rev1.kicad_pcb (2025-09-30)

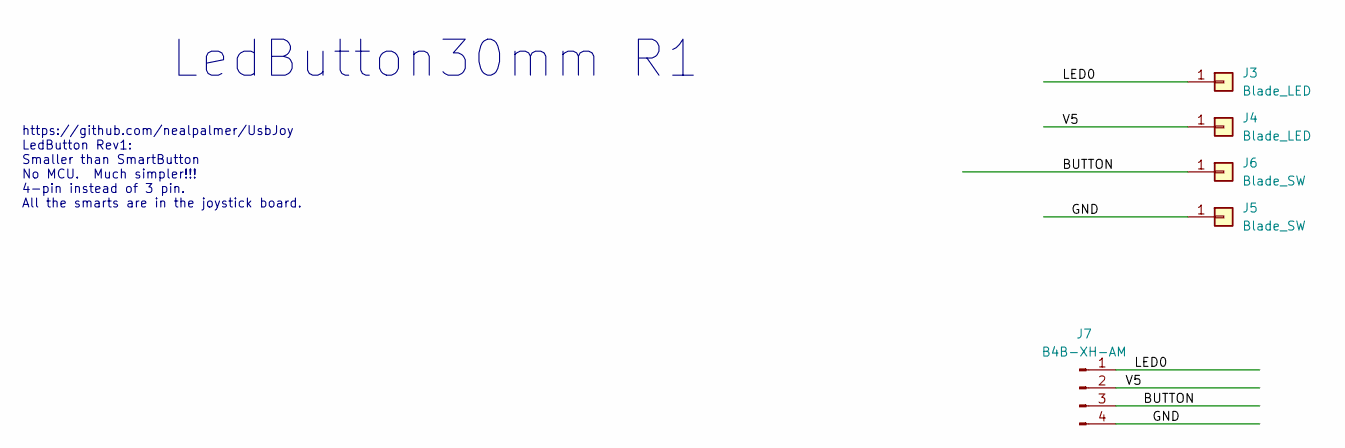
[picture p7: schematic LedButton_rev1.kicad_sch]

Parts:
J3, J4: Blade_LED; blade_3.75x1
J5, J6: Blade_SW; blade_3.75x1
J7: B4B-XH-AM; JST_XH_B4B-XH-AM_1x04_P2.50mm_Vertical

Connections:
/BUTTON: J6.1, J7.3
/GND: J5.1, J7.4
/LED0: J3.1, J7.1
/V5: J4.1, J7.2

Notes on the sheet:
https://github.com/nealpalmer/UsbJoy LedButton Rev1: Smaller than SmartButton No MCU. Much simpler!!! 4-pin instead of 3 pin. All the smarts are in the joystick board.
LedButton30mm R1

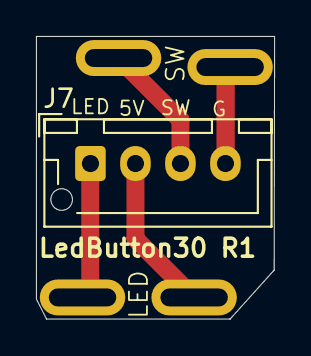
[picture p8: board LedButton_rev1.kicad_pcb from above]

Board: 2 copper layers, 13.2 x 15.7 mm, 5 parts (0 on the bottom side), 4 nets.

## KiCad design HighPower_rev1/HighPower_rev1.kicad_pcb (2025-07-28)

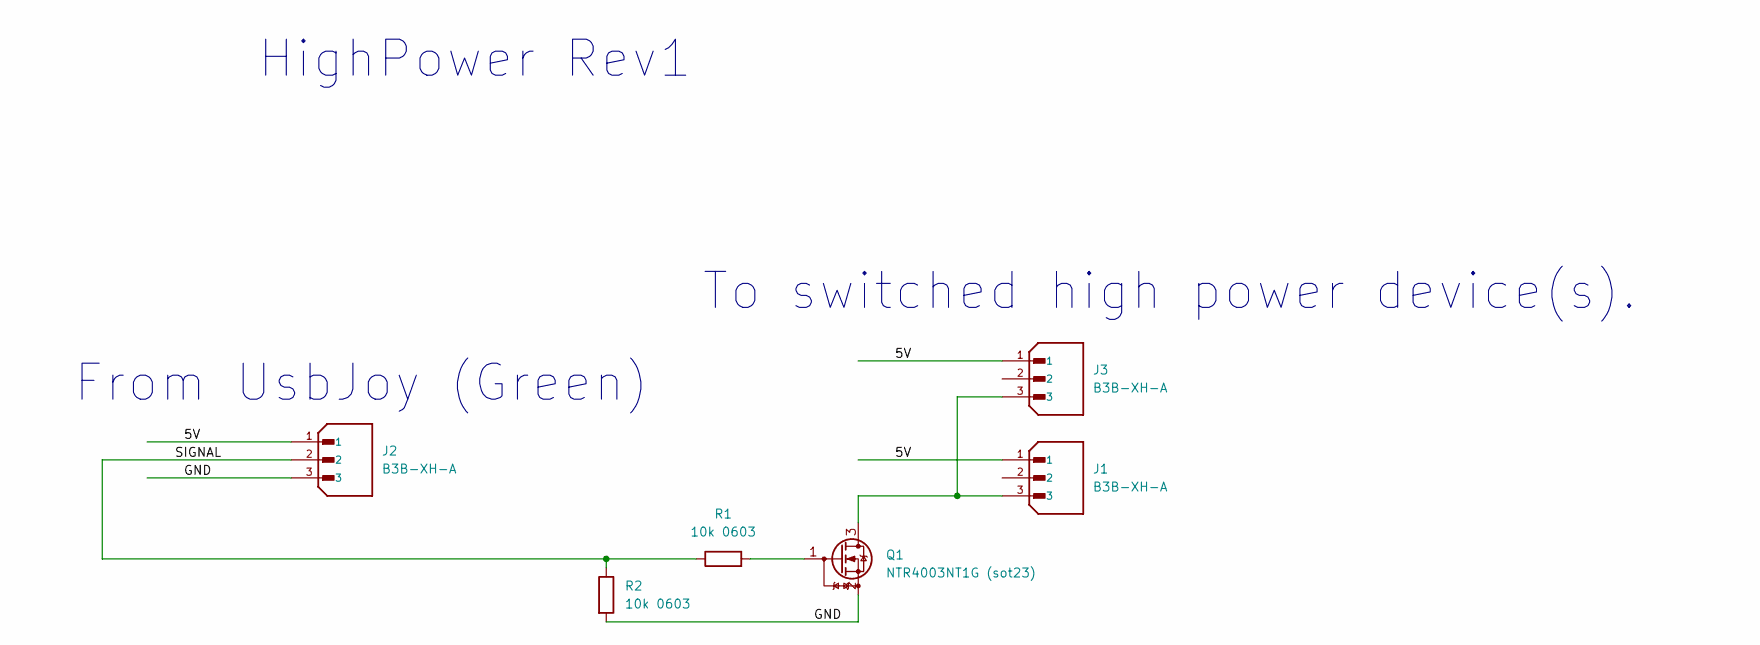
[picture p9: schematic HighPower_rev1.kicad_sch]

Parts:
J1, J2, J3: B3B-XH-A; JST_XH_B3B-XH-A_1x03_P2.50mm_Vertical; PARTREV 7/4/21
Q1: NTR4003NT1G (sot23); SOT-23
R1, R2: 10k 0603; C_0603_1608Metric_Pad1.08x0.95mm_HandSolder

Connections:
/5V: J1.1, J2.1, J3.1
/GND: J2.3, Q1.2 (S), R2.2
/SIGNAL: J2.2, R1.1, R2.1
unnamed: J1.3, J3.3, Q1.3 (D)
unnamed: Q1.1 (G), R1.2

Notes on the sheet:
HighPower Rev1
From UsbJoy (Green)
To switched high power device(s).

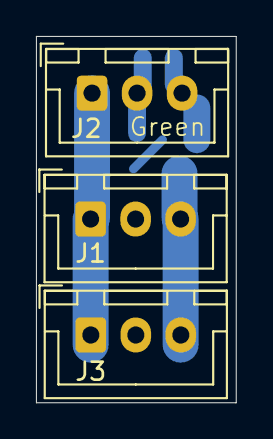
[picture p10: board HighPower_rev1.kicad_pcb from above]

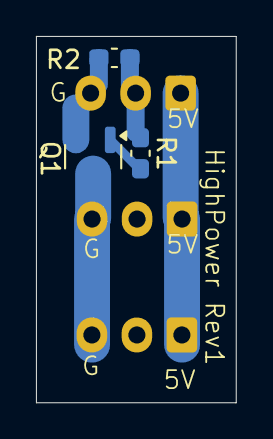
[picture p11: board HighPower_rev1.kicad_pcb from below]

Board: 2 copper layers, 11.1 x 20.4 mm, 6 parts (3 on the bottom side), 5 nets.

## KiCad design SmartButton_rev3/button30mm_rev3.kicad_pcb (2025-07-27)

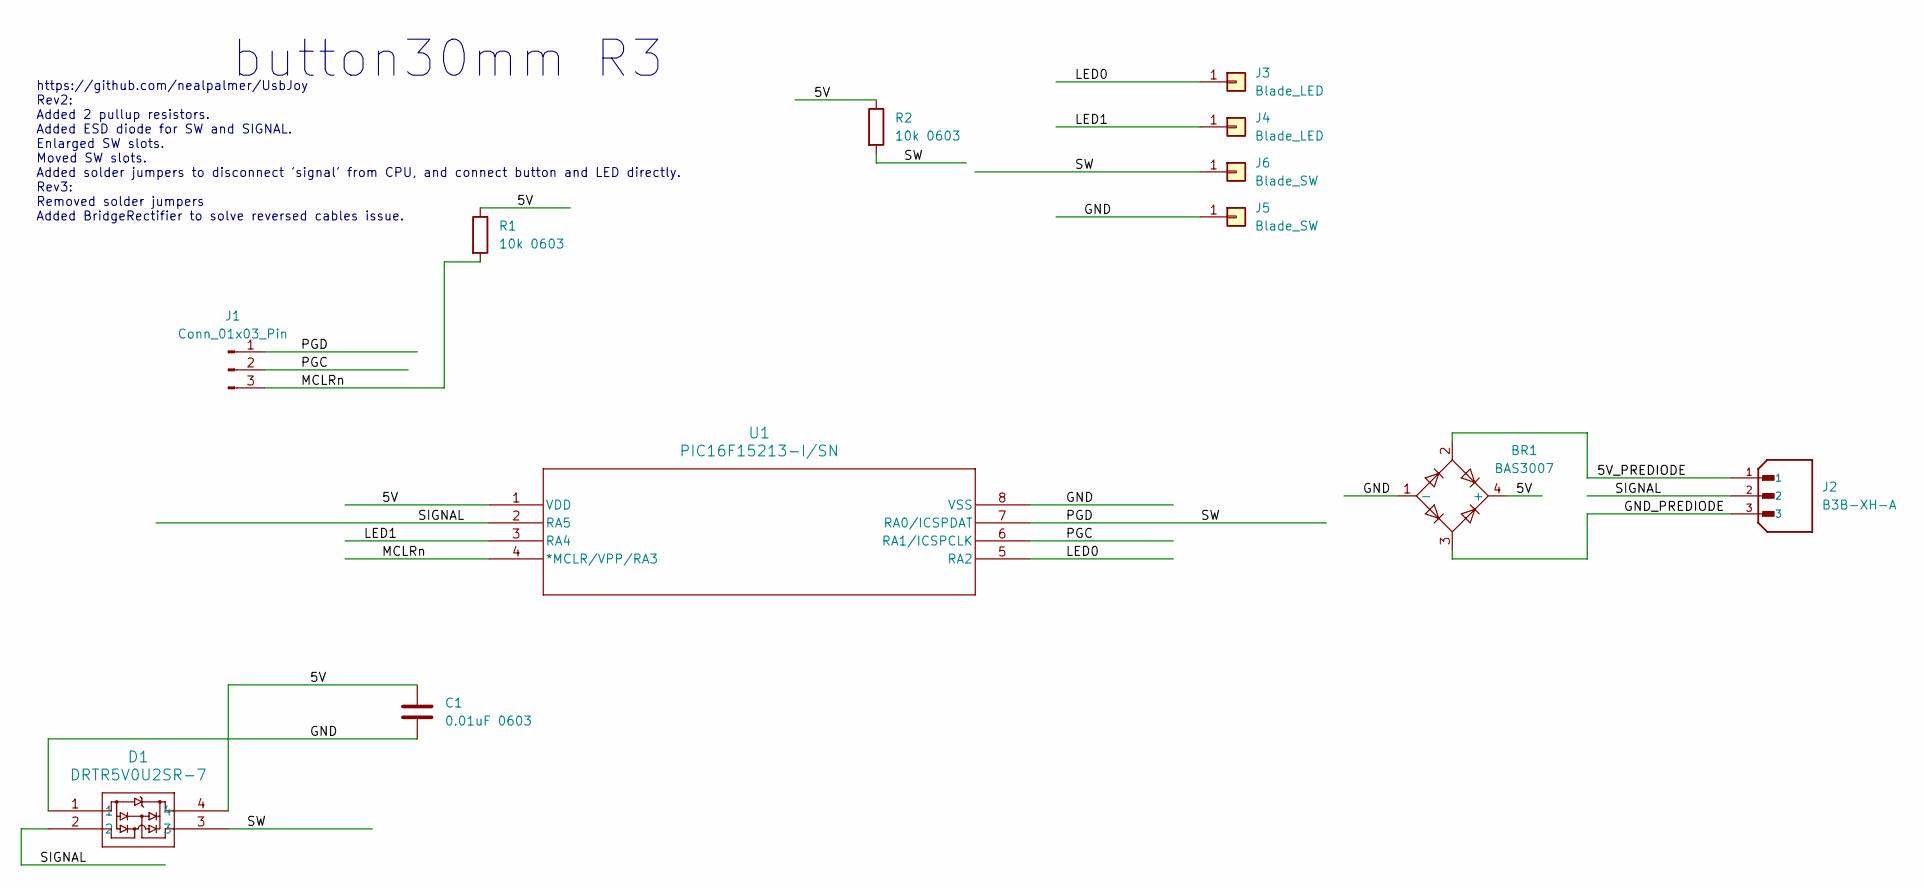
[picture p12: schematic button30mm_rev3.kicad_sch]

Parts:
BR1: BAS3007; SOT143_DIO
C1: 0.01uF 0603; C_0603_1608Metric_Pad1.08x0.95mm_HandSolder
D1: DRTR5V0U2SR-7; SOT143_DIO
J1: Conn_01x03_Pin; PinHeader_1x03_P2.54mm_Vertical
J2: B3B-XH-A; JST_XH_B3B-XH-A_1x03_P2.50mm_Vertical; PARTREV 7/4/21
J3, J4: Blade_LED; blade_3.75x1
J5, J6: Blade_SW; blade_3.75x1
R1, R2: 10k 0603; C_0603_1608Metric_Pad1.08x0.95mm_HandSolder
U1: PIC16F15213-I/SN; SOIC-8_3.9x4.9mm_P1.27mm

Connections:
/5V: BR1.4 (+), C1.1, D1.4, R1.1, R2.1, U1.1 (VDD)
/5V_PREDIODE: BR1.2, J2.1
/GND: BR1.1 (-), C1.2, D1.1, J5.1, U1.8 (VSS)
/GND_PREDIODE: BR1.3, J2.3
/LED0: J3.1, U1.5 (RA2)
/LED1: J4.1, U1.3 (RA4)
/MCLRn: J1.3, R1.2, U1.4 (*MCLR/VPP/RA3)
/PGC: J1.2, U1.6 (RA1/ICSPCLK)
/PGD: D1.3, J1.1, J6.1, R2.2, U1.7 (RA0/ICSPDAT)
/SIGNAL: D1.2, J2.2, U1.2 (RA5)

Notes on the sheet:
https://github.com/nealpalmer/UsbJoy Rev2: Added 2 pullup resistors. Added ESD diode for SW and SIGNAL. Enlarged SW slots. Moved SW slots. Added solder jumpers to disconnect 'signal' from CPU, and connect button and LED directly. Rev3: Removed solder jumpers Added BridgeRectifier to solve reversed 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
button30mm R3

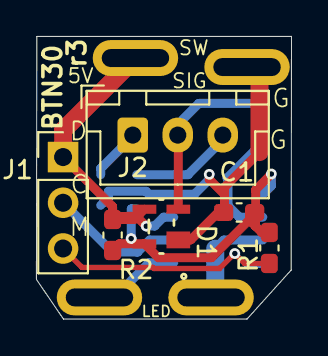
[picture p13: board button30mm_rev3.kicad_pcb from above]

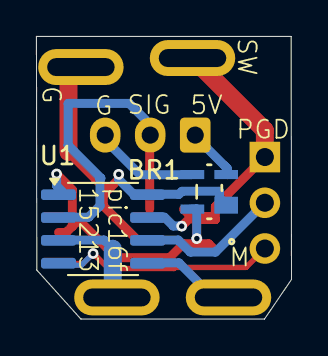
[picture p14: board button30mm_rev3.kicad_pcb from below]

Board: 2 copper layers, 14.2 x 15.7 mm, 12 parts (2 on the bottom side), 10 nets.

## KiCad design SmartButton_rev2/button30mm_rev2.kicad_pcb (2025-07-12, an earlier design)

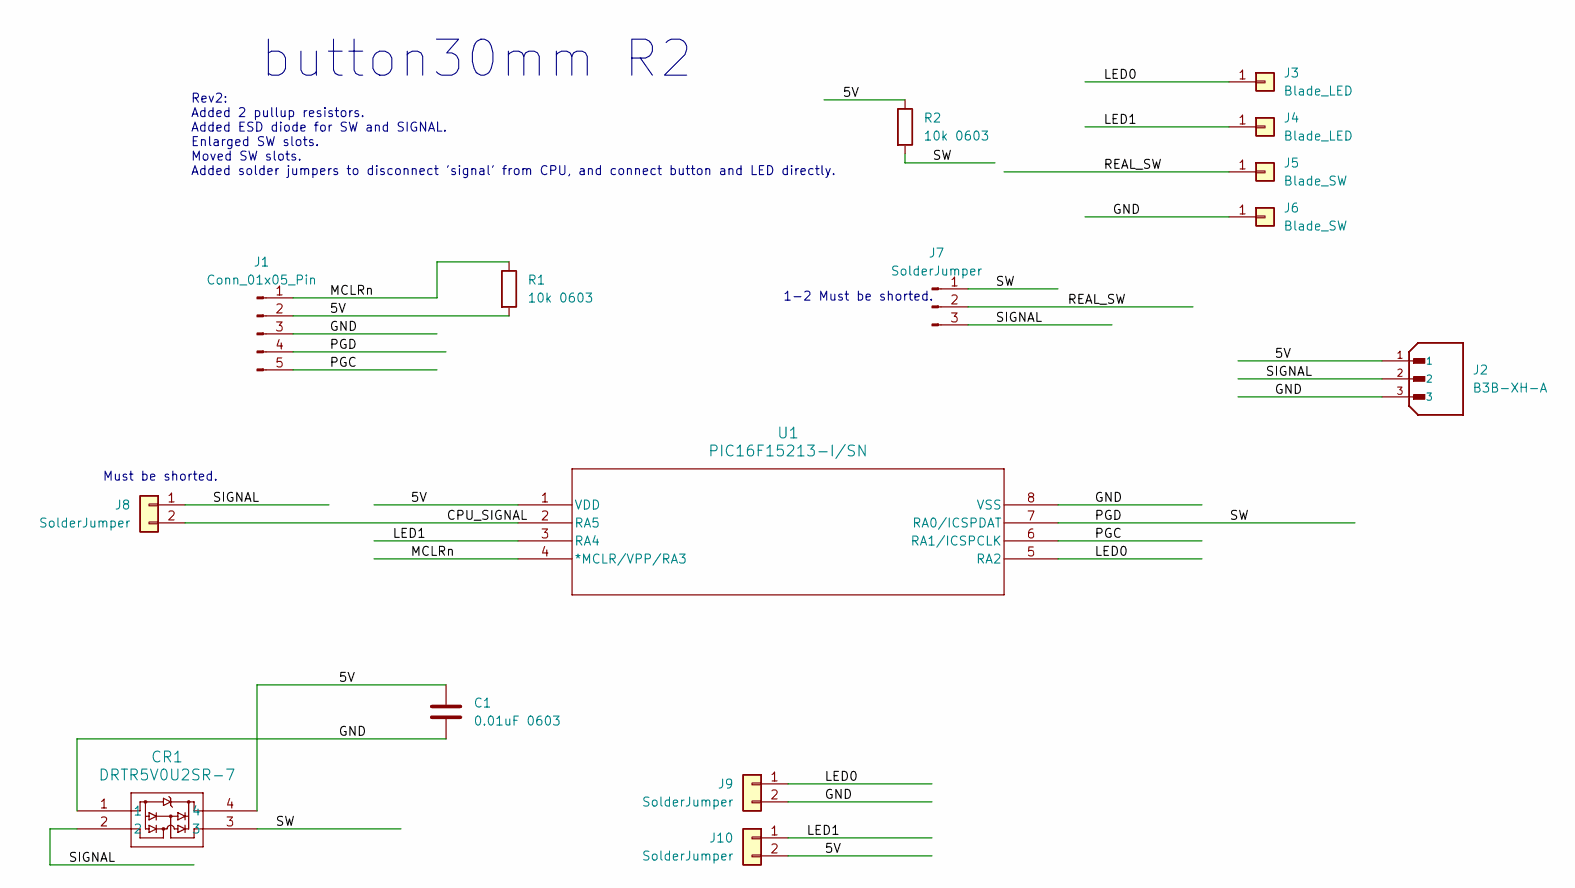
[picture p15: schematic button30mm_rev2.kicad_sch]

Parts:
C1: 0.01uF 0603; C_0603_1608Metric_Pad1.08x0.95mm_HandSolder
CR1: DRTR5V0U2SR-7; SOT143_DIO
J1: Conn_01x05_Pin; PinHeader_1x05_P2.54mm_Vertical
J2: B3B-XH-A; JST_XH_B3B-XH-A_1x03_P2.50mm_Vertical; PARTREV 7/4/21
J3, J4: Blade_LED; blade_3.75x1
J5, J6: Blade_SW; blade_3.75x1
J7: SolderJumper; SolderJumper-3_P1.3mm_Shorted_Pad0.8x0.4mm
J8: SolderJumper; SolderJumper-2_P1.3mm_Shorted_Pad0.4x0.8mm
J9, J10: SolderJumper; SolderJumper-2_P1.3mm_Open_Pad0.4x0.8mm
R1, R2: 10k 0603; C_0603_1608Metric_Pad1.08x0.95mm_HandSolder
U1: PIC16F15213-I/SN; SOIC-8_5.3x5.3mm_P1.27mm

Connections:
/5V: C1.1, CR1.4, J1.2, J2.1, J10.2, R1.2, R2.1, U1.1 (VDD)
/CPU_SIGNAL: J8.2, U1.2 (RA5)
/GND: C1.2, CR1.1, J1.3, J2.3, J6.1, J9.2, U1.8 (VSS)
/LED0: J3.1, J9.1, U1.5 (RA2)
/LED1: J4.1, J10.1, U1.3 (RA4)
/MCLRn: J1.1, R1.1, U1.4 (*MCLR/VPP/RA3)
/PGC: J1.5, U1.6 (RA1/ICSPCLK)
/PGD: CR1.3, J1.4, J7.1, R2.2, U1.7 (RA0/ICSPDAT)
/REAL_SW: J5.1, J7.2
/SIGNAL: CR1.2, J2.2, J7.3, J8.1

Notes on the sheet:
Must be shorted.
Rev2: Added 2 pullup resistors. Added ESD diode for SW and SIGNAL. Enlarged SW slots. Moved SW slots. Added solder jumpers to disconnect 'signal' from CPU, and connect button and LED directly.
button30mm R2
1-2 Must be shorted.

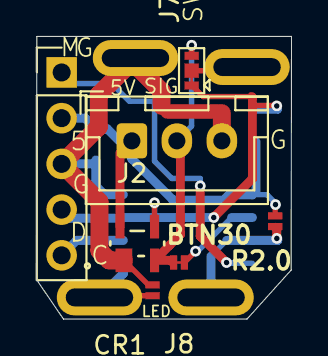
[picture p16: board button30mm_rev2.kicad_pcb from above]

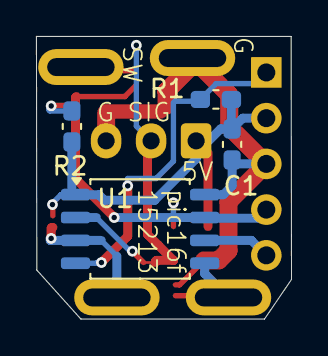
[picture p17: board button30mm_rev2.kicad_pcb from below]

Board: 2 copper layers, 14.2 x 15.7 mm, 15 parts (4 on the bottom side), 10 nets.

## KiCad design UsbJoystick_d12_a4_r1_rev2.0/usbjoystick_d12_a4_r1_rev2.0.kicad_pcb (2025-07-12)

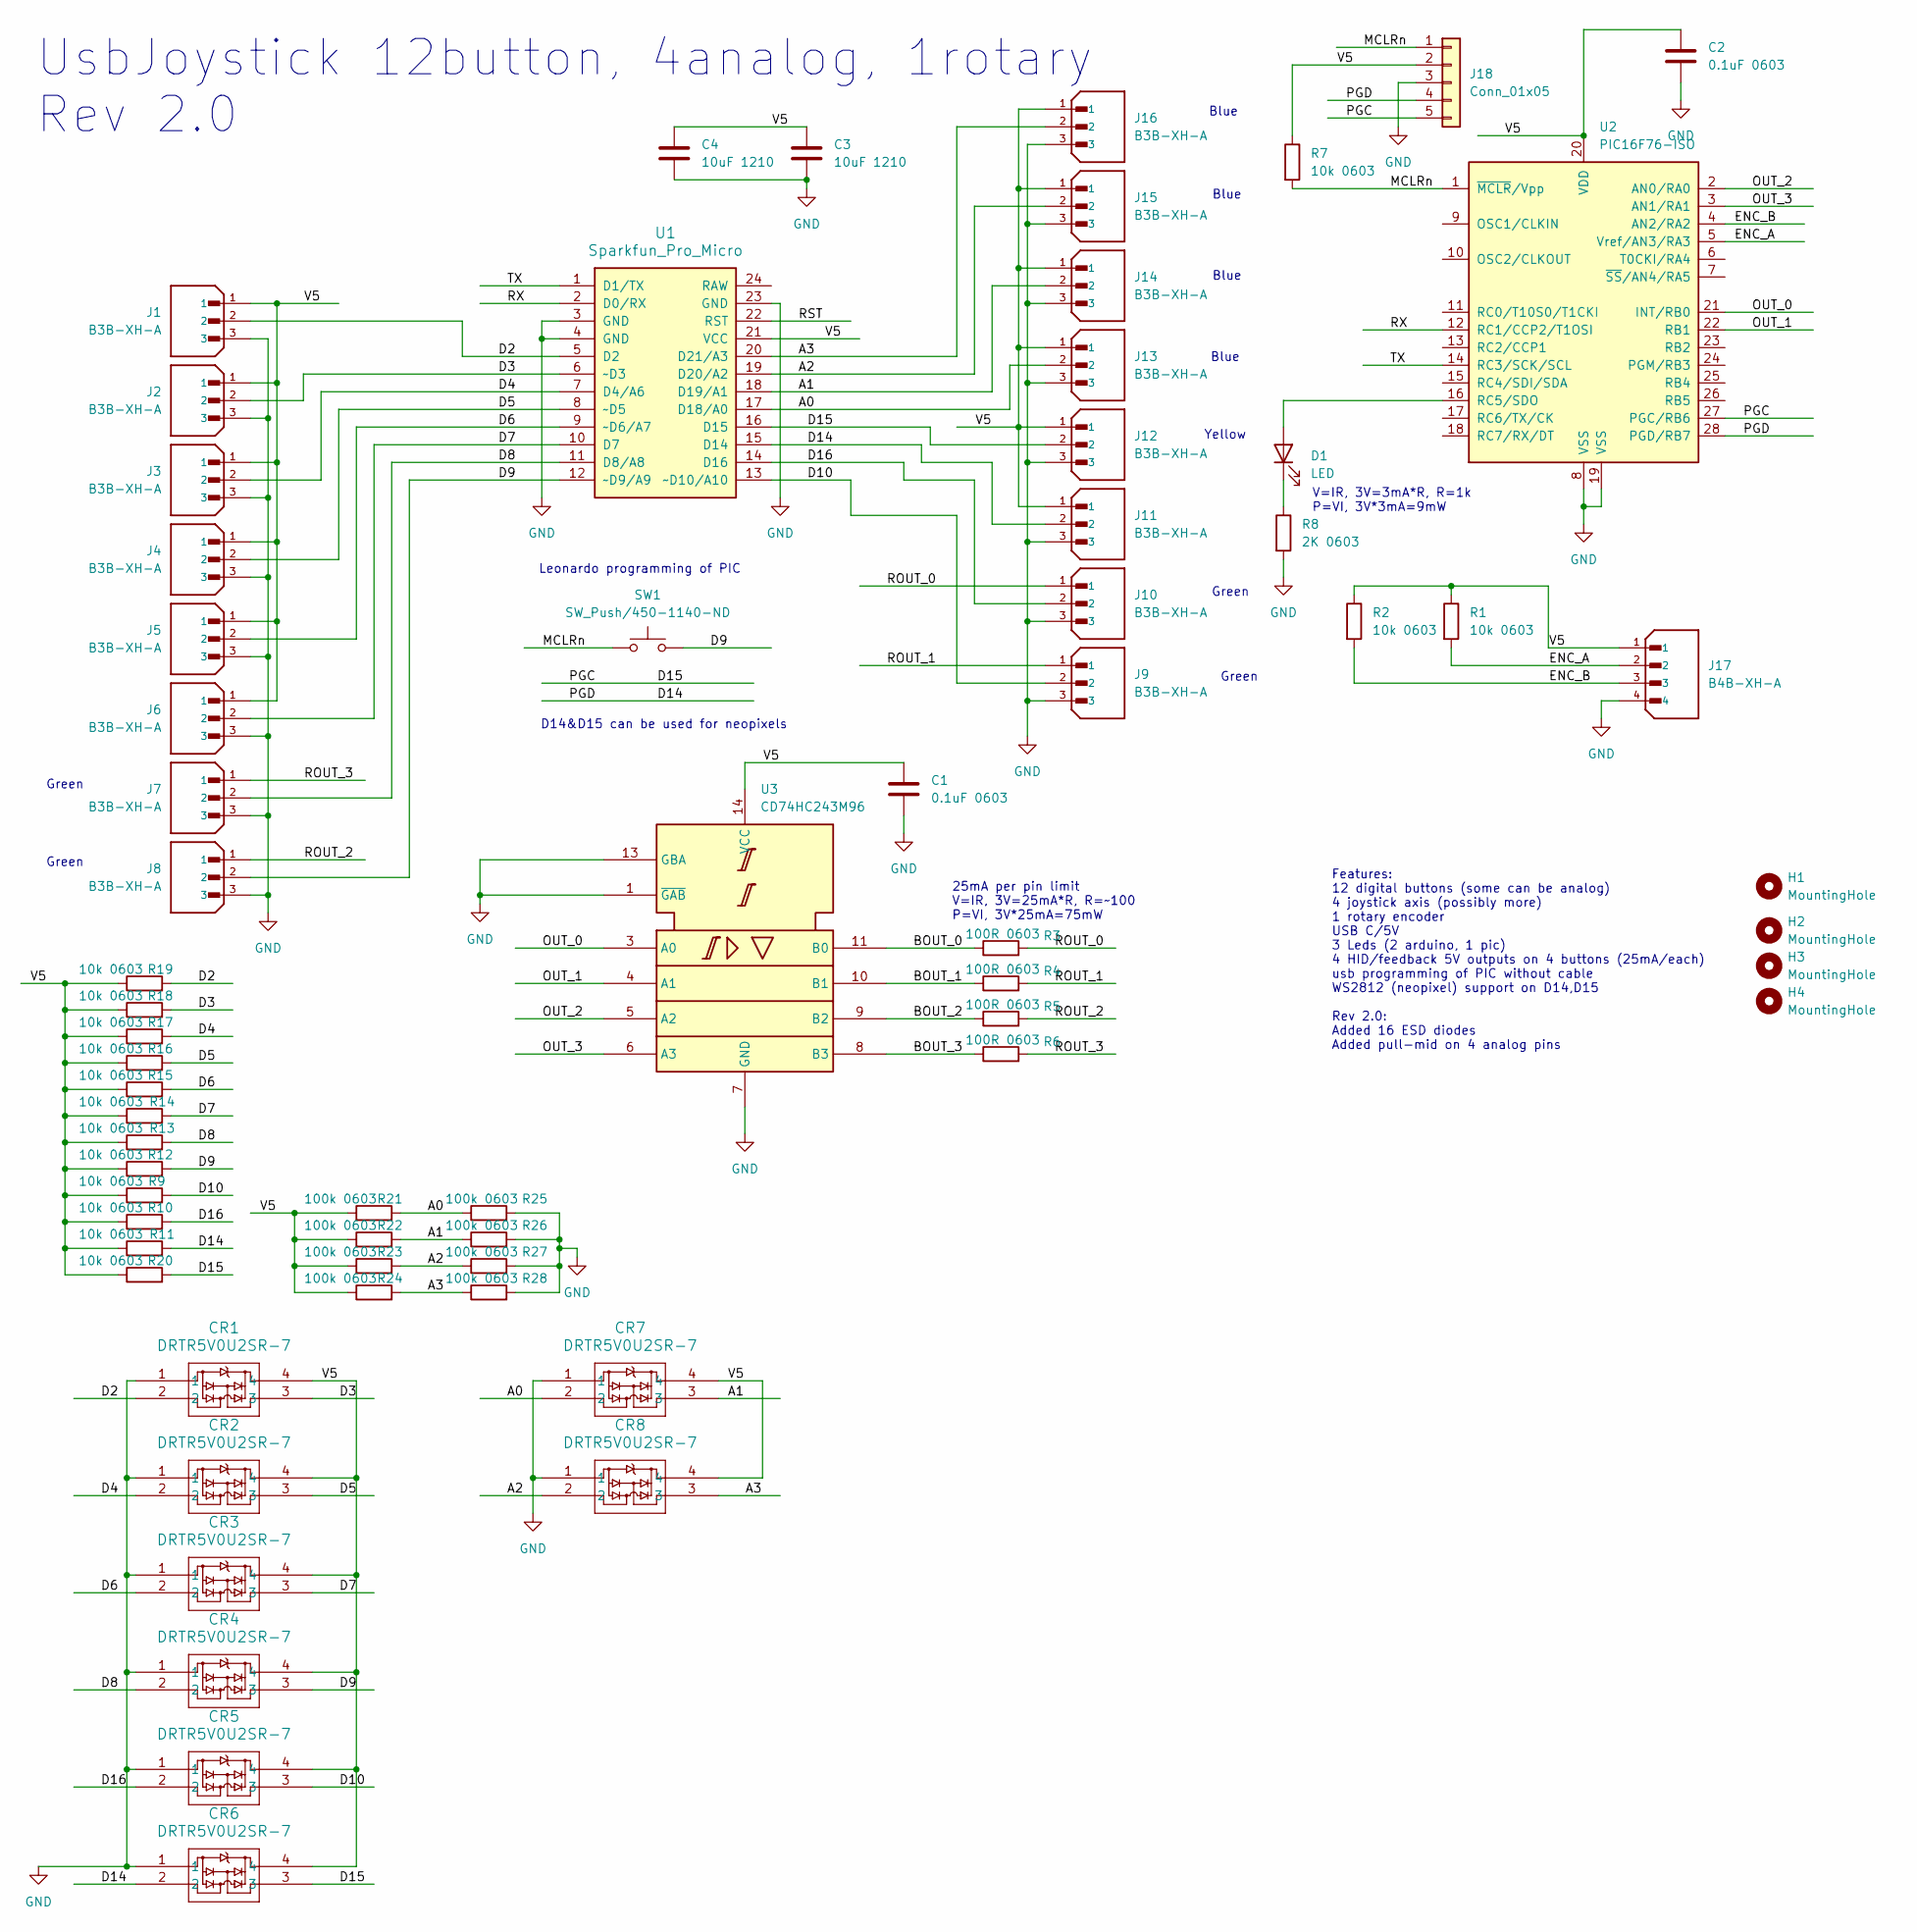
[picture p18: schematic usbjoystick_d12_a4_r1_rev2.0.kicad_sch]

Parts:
C1, C2: 0.1uF 0603; C_0603_1608Metric_Pad1.08x0.95mm_HandSolder
C3, C4: 10uF 1210; C_1210_3225Metric_Pad1.33x2.70mm_HandSolder
CR1, CR2, CR3, CR4, CR5, CR6, CR7, CR8: DRTR5V0U2SR-7; SOT-143_Handsoldering
D1: LED; LED_0603_1608Metric
H1, H2, H3, H4: MountingHole; MountingHole_3.2mm_M3
J1, J2, J3, J4, J5, J6, J7, J8, J9, J10, J11, J12, J13, J14, J15, J16: B3B-XH-A; JST_B3B-XH-A; PARTREV 7/4/21
J17: B4B-XH-A; JST_B4B-XH-A; PARTREV 7/4/21
J18: Conn_01x05; PinSocket_1x05_P2.54mm_Vertical
R1, R2, R7, R9, R10, R11, R12, R13, R14, R15, R16, R17, R18, R19, R20: 10k 0603; C_0603_1608Metric_Pad1.08x0.95mm_HandSolder
R3, R4, R5, R6: 100R 0603; C_0603_1608Metric_Pad1.08x0.95mm_HandSolder
R8: 2K 0603; C_0603_1608Metric_Pad1.08x0.95mm_HandSolder
R21, R22, R23, R24, R25, R26, R27, R28: 100k 0603; C_0603_1608Metric_Pad1.08x0.95mm_HandSolder
SW1: SW_Push/450-1140-ND; SW_SPST_FSMSM
U1: Sparkfun_Pro_Micro
U2: PIC16F76-ISO; SOIC-28W_7.5x17.9mm_P1.27mm
U3: CD74HC243M96; SO-14_3.9x8.65mm_P1.27mm

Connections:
/A0: CR7.2, J13.2, R21.2, R25.1, U1.17 (D18/A0)
/A1: CR7.3, J14.2, R22.2, R26.1, U1.18 (D19/A1)
/A2: CR8.2, J15.2, R23.2, R27.1, U1.19 (D20/A2)
/A3: CR8.3, J16.2, R24.2, R28.1, U1.20 (D21/A3)
/BOUT_0: R3.1, U3.11 (B0)
/BOUT_1: R4.1, U3.10 (B1)
/BOUT_2: R5.1, U3.9 (B2)
/BOUT_3: R6.1, U3.8 (B3)
/D2: CR1.2, J1.2, R19.2, U1.5 (D2)
/D3: CR1.3, J2.2, R18.2, U1.6 (~D3)
/D4: CR2.2, J3.2, R17.2, U1.7 (D4/A6)
/D5: CR2.3, J4.2, R16.2, U1.8 (~D5)
/D6: CR3.2, J5.2, R15.2, U1.9 (~D6/A7)
/D7: CR3.3, J6.2, R14.2, U1.10 (D7)
/D8: CR4.2, J7.2, R13.2, U1.11 (D8/A8)
/D9: CR4.3, J8.2, R12.2, SW1.2, U1.12 (~D9/A9)
/D10: CR5.3, J9.2, R9.2, U1.13 (~D10/A10)
/D14: CR6.2, J11.2, J18.4, R11.2, U1.15 (D14), U2.28 (PGD/RB7)
/D15: CR6.3, J12.2, J18.5, R20.2, U1.16 (D15), U2.27 (PGC/RB6)
/D16: CR5.2, J10.2, R10.2, U1.14 (D16)
/ENC_A: J17.2, R1.2, U2.5 (Vref/AN3/RA3)
/ENC_B: J17.3, R2.2, U2.4 (AN2/RA2)
/MCLRn: J18.1, R7.2, SW1.1, U2.1 (~MCLR/Vpp)
/OUT_0: U2.21 (INT/RB0), U3.3 (A0)
/OUT_1: U2.22 (RB1), U3.4 (A1)
/OUT_2: U2.2 (AN0/RA0), U3.5 (A2)
/OUT_3: U2.3 (AN1/RA1), U3.6 (A3)
/ROUT_0: J10.1, R3.2
/ROUT_1: J9.1, R4.2
/ROUT_2: J8.1, R5.2
/ROUT_3: J7.1, R6.2
/RST: U1.22 (RST)
/RX: U1.2 (D0/RX), U2.12 (RC1/CCP2/T1OSI)
/TX: U1.1 (D1/TX), U2.14 (RC3/SCK/SCL)
/V5: C1.1, C2.1, C3.1, C4.1, CR1.4, CR2.4, CR3.4, CR4.4, CR5.4, CR6.4, CR7.4, CR8.4, J1.1, J2.1, J3.1, J4.1, J5.1, J6.1, J11.1, J12.1, J13.1, J14.1, J15.1, J16.1, J17.1, J18.2, R1.1, R2.1, R7.1, R9.1, R10.1, R11.1, R12.1, R13.1, R14.1, R15.1, R16.1, R17.1, R18.1, R19.1, R20.1, R21.1, R22.1, R23.1, R24.1, U1.21 (VCC), U2.20 (VDD), U3.14 (VCC)
GND: C1.2, C2.2, C3.2, C4.2, CR1.1, CR2.1, CR3.1, CR4.1, CR5.1, CR6.1, CR7.1, CR8.1, J1.3, J2.3, J3.3, J4.3, J5.3, J6.3, J7.3, J8.3, J9.3, J10.3, J11.3, J12.3, J13.3, J14.3, J15.3, J16.3, J17.4, J18.3, R8.2, R25.2, R26.2, R27.2, R28.2, U1.3 (GND), U1.4 (GND), U1.23 (GND), U2.8 (VSS), U2.19 (VSS), U3.1 (~GAB), U3.7 (GND), U3.13 (GBA)
unnamed: D1.2 (A), U2.16 (RC5/SDO)
unnamed: D1.1 (K), R8.1

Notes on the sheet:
Leonardo programming of PIC
Green
Blue
Yellow
UsbJoystick 12button, 4analog, 1rotary Rev 2.0
D14&D15 can be used for neopixels
25mA per pin limit V=IR, 3V=25mA*R, R=~100 P=VI, 3V*25mA=75mW
Features: 12 digital buttons (some can be analog) 4 joystick axis (possibly more) 1 rotary encoder USB C/5V 3 Leds (2 arduino, 1 pic) 4 HID/feedback 5V outputs on 4 buttons (25mA/each) usb programming of PIC without cable WS2812 (neopixel) support on D14,D15 Rev 2.0: Added 16 ESD diodes Added pull-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
V=IR, 3V=3mA*R, R=1k P=VI, 3V*3mA=9mW



Board: 2 copper layers, 43.0 x 58.0 mm, 67 parts (29 on the bottom side), 37 nets.

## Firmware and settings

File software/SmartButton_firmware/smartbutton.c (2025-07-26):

#include <pic.h>
#include <stdint.h>
//#include <types.h>

#pragma config VDDAR = 1 // 5V voltage range
#pragma config CLKOUTEN = 1 // CLKOUT pin is a GPIO
//#pragma config RSTOSC = 2 // HFINTOSC at 1Mhz
#pragma config RSTOSC = 0 // HFINTOSC at 32Mhz
#pragma config FEXTOSC = 1 // oscillator not enabled

#pragma config STVREN = 1 // restup upon stack issues
#pragma config BORV = 0 // 2.85V brown out voltage
#pragma config BOREN = 3 // always enabled
#pragma config WDTE = 0 // always disabled
#pragma config PWRTS = 3 // always disabled
#pragma config MCLRE = 1 // MCLRn pin functionality

#pragma config LVP = 1 // low voltage programming
#pragma config WRTSAF = 1 // not write protected
#pragma config SAFEN = 0 // reserve StorageAreaFlash starting at address 0x780 for 128 words

#define signal LATA5
#define button RA0

//#define LEDA4
//#ifdef LEDA4
//#define led LATA4
//#else
//#define led LATA2
//#endif

uint32_t command_word=0xffffffff;
int8_t response_mode = 1;
uint8_t led_mode;
uint8_t toggle_button = 2;
uint8_t toggle_mode = 0; // this is for toggling the response signal every single query (for figuring out the min vs max pulse widths per port)
uint8_t toggle_mode_val = 0;

//#define NOP asm("nop")

#define PULSE_MIN 10
#define PULSE_SPLIT 31
#define PULSE_MAX 60

// values:
// bit 0, led off
// bit 0, led command_enable(d) (default config of the LED)
// bit 1, led off
// bit 1, led command_enable(d) (default config of the LED)

//uint8_t command_enabled = 1;
uint8_t toggle;
uint8_t virtual_button;

void __interrupt() isr() {
		// only process rising edge interrupts
	//if (IOCAF5) { // rising edge interrrupt on A5/'signal'
		if (response_mode) {
			signal = 0; // drive low
			for (char i=20;i!=0;i--)
				NOP();
#if 1 // set to 0 to display binary counter value on o-scope
			signal = (__bit)virtual_button; // & button; // variable length pulse based on button (but only sent when the incoming pulse is of an appropriate length)
#else
			// short: 0000_1111 = 0x0f = 15
			// long:  0010_1111 = 0x2f = 47
			if (1) {
				for (int i=7;i>=0;i--) {
					signal = 0;
					signal = 0;
					signal = TMR1L >> i;
					signal = TMR1L >> i;
					signal = TMR1L >> i;
					signal = 1;
				}
			} else {
				if ((command_word & 0xfffff00f) == 0x0000a003)
				for (int i=32;i>=0;i--) {
					signal = 0;
					signal = 0;
					signal = command_word >> i;
					signal = command_word >> i;
					signal = command_word >> i;
					signal = 1;
				}
			}
#endif
			for (char i=40;i!=0;i--)
				NOP();
			signal = 1; // tri-state 'signal'
			toggle = (toggle^1)&1;
		}
		toggle_mode_val ^= 1; // toggle the value every time (hopefully)

		if ((TMR1H>0) || (TMR1L<PULSE_MIN) || (TMR1L>PULSE_MAX) || (TMR1IF==1)) {
			command_word = 0xffffffff;
		} else {
			command_word = (command_word<<1);
			if (TMR1L < PULSE_SPLIT) {
					// received a '1'
				command_word++;
				//command_enabled = 1;
				//command_enabled = (TMR1L > PULSE_1);
			} else {
					// received a '0'
				//command_enabled = (TMR1L > PULSE_3);
			}
		}

		TMR1IF = 0; // clear timer overflow interrupt (especially after response has been sent)
		TMR1H = 0;
		TMR1L = 0;
		T1GCONbits.GGO = 1; // start single acquisition (after response has been sent)
		IOCAF5 = 0; // clear rising edge interrupt
	//}
}


#define LED_OFF 0
#define LED_ON 1
#define LED_PULSE 2 // 0.1s on when button initially pressed
#define LED_ON_PRESSED 3 // on when button is held
#define LED_FLASHING 4 // {0.1s/0.1s} flashing
#define LED_SIN 5 // always on with sin() brightness
#define LED_FLASHING_PRESSED 6 // flashing when button is pressed
#define LED_TOGGLE_LIT_STARTON 7 // each press toggles the state of the button, LED on when simulating pressed.
#define LED_TOGGLE_FLASHING 8 // each press toggles the state of the button, LED flashing when simulating pressed.
#define LED_TOGGLE_LIT_STARTOFF 9 // each press toggles the state of the button, LED on when simulating pressed.

#define PWM_ON 0x80 // 50% brightness
#define PWM_OFF 0x00

uint16_t ms_time=0;

// *******************************************
// *******************************************
// *******************************************
// *******************************************
// void main()
// *******************************************
// *******************************************
// *******************************************
// *******************************************
void main() {
int8_t last_button = 1;
int16_t timeout_command = 0;

// *******************************************
// setup oscillator to run 1Mhz HFINTOSC
// *******************************************
//OSCFRQ = 0; // 1Mhz 

led_mode = LED_PULSE; // default to pulsing the led when the button gets pressed
toggle_button = 2;

// *******************************************
// Setup pins
// *******************************************

// setup ‘button’ pin
//ANSELA0 = 0;
WPUA0 = 1;
TRISA0 = 1;

// setup ‘signal’ pin to the joystick controller board
//ANSELA5 = 0;
WPUA5 = 1;
ODCA5 = 1; // set as open-drain
signal = 1;
TRISA5 = 0; // drive the pin as an output
RA5PPS = 0; // LATA5 is source for the pin output

ANSELA = 0;


// setup ‘led’ pins
LATA4 = 0;
TRISA4 = 0;
// second LED pin
LATA2 = 0;
TRISA2 = 0;

// *******************************************
// drive one LED pin to GND, pullup the other, try both ways.
// The pullup connected to the 5V side of the LED should have a significant voltage droop.
// Whichever way has a lower voltage is the 5V side of the LED.
// *******************************************
ANSELA = 0;
WPUA4 = 1;
WPUA2 = 1;
uint8_t adc_vals[2];
for (int i=0;i<2;i++) {
	if (i==0) {
		ANSELA = 0x04;
		TRISA2 = 1; // let it get pulled high
		TRISA4 = 0; // drive to GND
		ADCON0bits.CHS = 2; // RA2
	} else {
		ANSELA = 0x10;
		TRISA2 = 0; // drive to GND
		TRISA4 = 1; // let it get pulled high
		ADCON0bits.CHS = 4; // RA4
	}
	ADCON1bits.CS = 2; // Fosc/32 (32us)
	ADCON1bits.FM = 0; // result: {ADRESH[7:0], ADRESL[7:6]}
	ADCON1bits.PREF = 0; // 5V is Vref+
	ADCON0bits.ON = 1;
	ADCON0bits.GO = 1;
	while (ADCON0bits.GO==1)
		;
	adc_vals[i] = ADRESH;
}
ADCON0bits.ON = 0;
ANSELA = 0;
WPUA4 = 0;
WPUA2 = 0;
TRISA2 = 0;
TRISA4 = 0;
LATA2 = 0;
LATA4 = 0;

if (adc_vals[0] < adc_vals[1]) {
		// A2 is the 5V side of the LED
		RA2PPS = 3; // use PWM3
} else {
		// A4 is the 5V side of the LED
		RA4PPS = 3; // use PWM3
}
PWM3DCH = 0; // turn off the LED
PWM3DCH = 0x10; // turn on the LED

// *******************************************
// setup timer0 to count 0.001s
// *******************************************
T0CON0bits.OUTPS = 0; // no postscalar
T0CON1bits.CS = 4; // LFINTOSC (32khz)
T0CON1bits.ASYNC = 0; // resynchronized to Fosc
T0CON1bits.CKPS = 0; // 1:1 prescale
T0CON0bits.MD16 = 0; // 8-bit mode
TMR0H = 32-1; // count 32 edges of the clock
T0CON0bits.EN = 1;

// *******************************************
// setup timer1 to time the low pulse on ‘signal’
// *******************************************
T1GCONbits.GTM = 0; // 
T1GCONbits.GPOL = 0; // enable when ‘signal’ is low
T1GCONbits.GSPM = 1; // single acquisition enable
T1GATE = 0; // gate signal from from T1GPPS
T1GPPS = 5; // RA5 = ‘signal’ pin;
TMR1L = 0;
TMR1H = 0;
T1CLK = 2; // HFINTOSC (32Mhz) is clock source 
T1CONbits.CKPS = 0;
T1CONbits.nSYNC = 1; // synchronize the sampling clock with system clock
T1GCONbits.GE = 1;
TMR1IF = 0; // clear overflow interrupt flag
TMR1IE = 0; // disable overflow interrupt
T1CONbits.ON = 1;
T1GCONbits.GGO = 1; // start single acquisition


// *******************************************
// setup timer2/pwm for led output
// *******************************************

T2PR = 0xfe; // longest PWM period == 10'b1111_1111_11
T2CLKCON = 1; // use Fosc/4
T2HLTbits.MODE = 0; // free-run mode
T2HLTbits.PSYNC = 1;
T2CONbits.CKPS = 1; // 1:1 prescale
T2CONbits.ON = 1; // start the timer

//PWM3DCH = 0xf0; // long pulse width
PWM3DCH = PWM_OFF; // no pulse width
PWM3DCL = 0; // only [7:6] are used
PWM3CONbits.EN = 1;

//PWM3DCH = PWM_OFF; // turn off the LED
PWM3DCH = PWM_ON; // turn on the LED

// *******************************************
// enable rising edge interrupt for A5
// *******************************************
IOCAP = 0;
IOCAN = 0;
IOCAP5 = 1; // A5 rising edge interrupt (end of pulse, after timing has completed)
IOCIE = 1;
INTCONbits.GIE = 1;

	// ****************************
	// process button press, LED output, and signal reception
	// ****************************
 while (1) {
	 uint32_t cmd = command_word;
	if ((cmd & 0xfffff00f) == 0x0000a003) {
		response_mode = 1;
		timeout_command = 0;
		toggle_mode = (cmd>>11)&1;

		// ************
		// decode 32-bit words from Arduino Leonardo (usb joystick controller)
		// 16'b0
		// 4'b1010
		// 4'b0000
		// 4'b led_mode
		// 4'b0011
		// ************
		led_mode = (cmd>>4)&0xf;
	}

		// ************
		// count 0.001s increments
		// ************
	if (TMR0IF) {
		TMR0IF=0; // clear interrupt flag
		ms_time++;
		timeout_command++;
		if (timeout_command > 4000) {
			timeout_command = 4000;
			response_mode = 0;
		}
	}

		// ************
		// Send button in non-response mode (this should never be used by our controller)
		// ************
	if (response_mode==0)
		signal = button; // open-drain always drive the button input to the pin.
						 
		// ************
		// Drive the LED
		// ************
#if 0
	PWM3DCH = PWM_ON; // mid brightness LED
#else
	if (toggle_mode) {
		virtual_button = toggle_mode_val;
	} else {
	switch (response_mode /*command_enabled*/ ? led_mode : LED_OFF) {
		case LED_OFF: PWM3DCH = PWM_OFF; virtual_button=button; break;
		case LED_ON: PWM3DCH = PWM_ON; virtual_button=button; break;
		case LED_PULSE:
			if (button==1) {
					// button not pressed
				ms_time = 0;
				TMR0L = 0; // restart the 0.1s timer
				PWM3DCH = PWM_OFF; // turn off LED
				last_button = 1;
			} else {
					// button is pressed
				if (ms_time>100)
					PWM3DCH = PWM_OFF; // turn off LED after 100ms
				if (last_button==1)
					PWM3DCH = PWM_ON; // turn on LED (for 100ms)
				last_button = 0;
			}
			virtual_button = button;
			break;
		case LED_ON_PRESSED:
			PWM3DCH = ((button==0) ? PWM_ON : PWM_OFF);
			virtual_button = button;
			break;
		case LED_FLASHING:
			PWM3DCH = (((ms_time>>7)&1) ? PWM_ON : PWM_OFF);
			virtual_button = button;
			break;
		case LED_FLASHING_PRESSED:
			if (button==1)
				PWM3DCH = PWM_OFF; // led off
			else
				PWM3DCH = (((ms_time>>7)&1) ? PWM_ON : PWM_OFF);
			virtual_button = button;
			break;
		case LED_SIN:
			{
				uint8_t cycle = (uint8_t)(ms_time>>7);
				switch (cycle & 0xf) {
					case 0: cycle = 0x00 | 0x18; break;
					case 1: case 15:cycle = 0x20 | 0x18; break;
					case 2: case 14:cycle = 0x40 | 0x18; break;
					case 3: case 13:cycle = 0x60 | 0x18; break;
					case 4: case 12:cycle = 0x80 | 0x18; break;
					case 5: case 11:cycle = 0xa0 | 0x18; break;
					case 6: case 10:cycle = 0xc0 | 0x18; break;
					case 7: case 9: cycle = 0xd0 | 0x18; break;
					case 8: cycle = 0xff | 0x18; break;
				}
				PWM3DCH = cycle;
			}
			virtual_button = button;
			break;
		case LED_TOGGLE_LIT_STARTON:
		case LED_TOGGLE_LIT_STARTOFF:
		case LED_TOGGLE_FLASHING:
			if (toggle_button>1)
				toggle_button = ((led_mode==LED_TOGGLE_LIT_STARTOFF) ? 1 : 0);

			if (ms_time > 250) {
				if ((last_button==1) && (button == 0)) {
					toggle_button = (toggle_button==0 ? 1 : 0);
					ms_time = 0;
				}
				last_button = button;
				if (ms_time > 250+200)
					ms_time = 250; // make a toggling pattern.
			}
			if (toggle_button==1) 
				PWM3DCH = PWM_OFF;
			else if ((led_mode==LED_TOGGLE_LIT_STARTON) || (led_mode==LED_TOGGLE_LIT_STARTOFF))
				PWM3DCH = PWM_ON/2;
			else
				PWM3DCH = (ms_time < 250+100) ? PWM_ON/2 : PWM_OFF;

			virtual_button = toggle_button;
			break;
		Default:
			PWM3DCH = ((button==0) ? PWM_ON : PWM_OFF);
			virtual_button = button;
	}
	}
#endif
 }
}

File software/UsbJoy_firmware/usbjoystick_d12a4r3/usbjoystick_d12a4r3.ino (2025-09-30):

// Make sure to edit arduino\avr\variants\leonards\pins_arduino.h and change LED_BUILT_RX and LED_BUILTIN_TX to 13
// And: TXLED0 to PORTD |= 0
// And: TXLED1 to PORTD &= 0xff
// And: RXLED0 to PORTB |= 0
// And: RXLED1 to PORTB &= 0xff
#include <Arduino.h>
#include <EEPROM.h>
#include <FastGPIO.h>
#include "Joystick.h"

#undef LED_BUILTIN_RX
#undef LED_BUILTIN_TX
#define LED_BUILTIN_myRX 17
#define LED_BUILTIN_myTX 30

uint8_t prog_pic = 0;  // stop driving upper 2 button outputs

#define BUTTON_COUNT 12
#define IDBUTTON_COUNT 4
#define TOGGLING_BUTTON_COUNT 1 // can be set to 1 or 0
#define ENCODER_LIMIT (600*4)
#define SAMPLES 25 // how many samples to grab to determine value(duration) of bit - 25 seems to work really well

struct {
	uint8_t len;
	uint8_t id; // 4-bits to set upper 4 id_buttons
	uint8_t neopixel_count;
	uint8_t led_mode[BUTTON_COUNT];
	uint8_t inv[5]; // invert the direction of the 4 analog inputs, and the encoder
	uint8_t pwren;
	uint8_t sb_mid[BUTTON_COUNT];
	uint8_t linearize;
	uint8_t is_dumb_button[BUTTON_COUNT];
} ee;

enum { // list of LED states for smart buttons
	LED_OFF,
	LED_ON,
	LED_ON_100MS, // on for 100ms when pressed
	LED_ON_PRESSED,
	LED_FLASHING,
	LED_SIN,
	LED_FLASHING_PRESSED,
	LED_TOGGLE_LIT_STARTON,
	LED_TOGGLE_FLASHING,
	LED_TOGGLE_LIT_STARTOFF,
	LED_NONE
};

uint8_t buttons[BUTTON_COUNT] = {2,3,4,5,6,7,8,9,10,16,14,15};
uint8_t analogin[4] = {A0,A1,A2,A3};

uint8_t led_state[BUTTON_COUNT];
int8_t smartbutton_test=0;
uint8_t responselen_min[BUTTON_COUNT];
uint8_t responselen_max[BUTTON_COUNT];
uint8_t neopixel_pattern = 1; // light blue
uint8_t debug = 0;
uint8_t last_count = 0;
uint8_t voltage_enables;

#define PGC 15
#define PGD 14
#define MCLR 9

Joystick_ joystick(
	JOYSTICK_DEFAULT_REPORT_ID, JOYSTICK_TYPE_JOYSTICK,
	BUTTON_COUNT + IDBUTTON_COUNT + TOGGLING_BUTTON_COUNT, 0, 
	true, true, true, // X and Y and Z axis
	true, true, true, // Rx and Ry axis, Rz axis (for higher resolution encoder)
	false, false, // no rudder nor throttle
	false, false, false // no accel, brake, steering
	);

uint8_t data[32];
int previousStates[6];
int neopixel_repeat_timer;

void ee_read(void);
void ee_update(void);

void setup() {
  // put your setup code here, to run once:
  Serial.begin(57600); // USB-uart
  Serial1.begin(57600); // RX/TX pins - uart
  //Serial1.begin(9600); // RX/TX pins - uart
  pinMode(LED_BUILTIN_myTX, OUTPUT);
  pinMode(LED_BUILTIN_myRX, OUTPUT);
  joystick.begin(false); // auto=false
  joystick.setXAxisRange(0,1023);
  joystick.setYAxisRange(0,1023);
  joystick.setZAxisRange(0,ENCODER_LIMIT-1); // rotary encoder
  joystick.setRxAxisRange(0,1023);
  joystick.setRyAxisRange(0,1023);
  joystick.setRzAxisRange(0,199); // rotary encoder LSB values only (for FRC controller which has a range of -1.00 to 1.00 = 200 values total)
  DynamicHID().prepareOutput(data, sizeof(data));

  ee_read(); // fetch the parameters from the internal eeprom

  for (uint8_t btn=0;btn<BUTTON_COUNT;btn++) {
	pinMode(buttons[btn],INPUT_PULLUP);
	led_state[btn] = ee.led_mode[btn];
		// set a reasonable value in the eeprom, if it was out of range
	if (led_state[btn]>=LED_NONE) {
		ee.led_mode[btn] = LED_ON_100MS;
		led_state[btn] = LED_ON_100MS;
	}
		// set a reasonable value in the eeprom
	if ((ee.sb_mid[btn]<3) || (ee.sb_mid[btn]>=SAMPLES-2)) {
			// the expected response lengths vary by pin (arduino library speeds)
		ee.sb_mid[btn] = ((((0xe65 >> btn)&1)==0) ? 7 : 11);
	}
	if (ee.is_dumb_button[btn]>1)
		ee.is_dumb_button[btn] = 0; // default all to smart buttons
  }
  for (uint8_t i=0;i<4;i++) {
	pinMode(analogin[i],INPUT_PULLUP);
  }

	// setup the neopixels
  if (ee.neopixel_count==0xff) {
		ee.neopixel_count=0;
  }
  Serial1.write('n');
  Serial1.println(ee.neopixel_count, HEX);
  neopixel_repeat_timer = millis()+10000;

	// Set the Green connector's power enables
  Serial1.write('v');
  Serial1.println(voltage_enables = (ee.pwren&0xf),HEX);

		// set the static ID buttons (this should only have to happen upon startup, but it doesn't cost much here)
  for (uint8_t id_btn=0;id_btn<IDBUTTON_COUNT;id_btn++) {
	joystick.setButton(id_btn+BUTTON_COUNT, (ee.id>>id_btn)&1);
  }

  if (ee.linearize>0xf)
	ee.linearize = 0;

  ee_update();
}

int32_t next_inc=0;
int16_t pic_inc=0;

int16_t encoder = 0; // accumulator for PIC UART data
int8_t uart_value=0; // accumulator for UART data
int32_t uart_value32=0; // accumulator for UART data
char uart_command;

char txled = 0;
char rxled = 0;

char command_index = 0;

void set_pulse(char pinnum,char len)
{
 switch(pinnum) {
		// drive low for a while, then drive high, and immediately tri-state.  This way the pullup resistor won't change the pulse time as much.
	case 2: while((len--)) FastGPIO::Pin<2>::setOutput(0); FastGPIO::Pin<2>::setOutput(1); FastGPIO::Pin<2>::setInputPulledUp(); break;
	case 3: while((len--)) FastGPIO::Pin<3>::setOutput(0); FastGPIO::Pin<3>::setOutput(1); FastGPIO::Pin<3>::setInputPulledUp(); break;
	case 4: while((len--)) FastGPIO::Pin<4>::setOutput(0); FastGPIO::Pin<4>::setOutput(1); FastGPIO::Pin<4>::setInputPulledUp(); break;
	case 5: while((len--)) FastGPIO::Pin<5>::setOutput(0); FastGPIO::Pin<5>::setOutput(1); FastGPIO::Pin<5>::setInputPulledUp(); break;
	case 6: while((len--)) FastGPIO::Pin<6>::setOutput(0); FastGPIO::Pin<6>::setOutput(1); FastGPIO::Pin<6>::setInputPulledUp(); break;
	case 7: while((len--)) FastGPIO::Pin<7>::setOutput(0); FastGPIO::Pin<7>::setOutput(1); FastGPIO::Pin<7>::setInputPulledUp(); break;
	case 8: while((len--)) FastGPIO::Pin<8>::setOutput(0); FastGPIO::Pin<8>::setOutput(1); FastGPIO::Pin<8>::setInputPulledUp(); break;
	case 9: while((len--)) FastGPIO::Pin<9>::setOutput(0); FastGPIO::Pin<9>::setOutput(1); FastGPIO::Pin<9>::setInputPulledUp(); break;
	case 10: while((len--)) FastGPIO::Pin<10>::setOutput(0); FastGPIO::Pin<10>::setOutput(1); FastGPIO::Pin<10>::setInputPulledUp(); break;
	case 14: while((len--)) FastGPIO::Pin<14>::setOutput(0); FastGPIO::Pin<14>::setOutput(1); FastGPIO::Pin<14>::setInputPulledUp(); break;
	case 15: while((len--)) FastGPIO::Pin<15>::setOutput(0); FastGPIO::Pin<15>::setOutput(1); FastGPIO::Pin<15>::setInputPulledUp(); break;
	case 16: while((len--)) FastGPIO::Pin<16>::setOutput(0); FastGPIO::Pin<16>::setOutput(1); FastGPIO::Pin<16>::setInputPulledUp(); break;
 }
}
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

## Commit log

2025-07-13 Add files via upload
    Added a 3d mount for UsbJoy to a 30mm SmartButton.
    [usb_joystick_mount.scad, usb_joystick_mount_horizontal.stl, usb_joystick_mount_vertical.stl]
2025-07-16 Updated the schematic to have the borders.
2025-07-17 Added PIC programming .HEX files for both boards.
2025-07-22 Added a 3dprinted tool to help unscrew the 30mm buttons from a panel (the nut has ribs and it gets stuck, so unscrew the button from the nut with a tool instead).
    [unscrew_30mm_button.scad]
2025-07-24 Fixed a printf typo
2025-07-26 Fixed arduino compile. Added toggle with default on and off.
    [DynamicHID.h, Joystick.h, main.cpp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]
2025-07-27 Fixed non-smart-button functionality.
2025-07-27 New SmartButton schematic+pcb rev3
    Added a bridge rectifier to fix the reversed cable issue.
    Removed 5V/GND from programming header (use the signal cable now).
    [button30mm_rev3.kicad_pcb, button30mm_rev3.kicad_sch]
2025-07-27 Finished the layout
    [button30mm_rev3.kicad_pcb, button30mm_rev3.kicad_sch]
2025-07-28 Added a higher switched power board.
    [HighPower_rev1.kicad_pcb, HighPower_rev1.kicad_sch]
2025-08-08 Add higher resolution for the rotary encoder with FRC driverstation.
    Added the RZ axis to have the full resolution of the encoder when FRC DriverStation converts the axis to -1.00 to 1.00 (only 200 values). Software has to combine both values together to the full rang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
2025-09-30 Added heat set nuts
    Added heat set nuts, so that the nylock nuts can be skipped.
    [usb_joystick_mount.scad, usb_joystick_mount_vertical.stl]
2025-09-30 Added simple led-button board.
    Added a PCB to get to a simple connector (without an additional pic in the button).
    [LedButton_rev1.kicad_pcb, LedButton_rev1.kicad_sch]
2025-09-30 Added a linear pot linearizer, added setting for dumb buttons.
    Dumb buttons were being driven, and generating long pulses, causing glitches.
    Some 'linear' pots were returning non-linear values. Added a table to fix it.
    [usbjoystick_d12a4r3.ino]
2026-10-23 Added an option to have a 2.5V fixed reference joystick input (i.e. cancel out VCC influence on it).
    Read VCC to calibrate, so that a fixed voltage joystick (magnetic instead of potentiometer) can have less VCC jitter.
    Added centering, and limits calibration for fixed voltage joystick.
2026-10-23 Fixed clearing of 2.5V joystick values.
    Fixed clearing of 2.5V joystick values.
    Updated the help output to include clearing.
2026-10-23 Added a USB descriptor serial number that corresponds to the upper 4-bit ID.
    Added a USB descriptor serial number that corresponds to the upper 4-bit ID.
    This should make it possible for an OS to identify which USBJoy is plugged in for the updated FRC driver-station 2027.
2026-10-27 Split 4 analog inputs into individually controlled fixed voltage references.
    Split 4 analog inputs into individually controlled fixed voltage references.
